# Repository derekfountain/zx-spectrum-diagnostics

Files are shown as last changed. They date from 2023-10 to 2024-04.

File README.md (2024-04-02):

# 16K/48K ZX Spectrum Diagnostics Board

This is a hardware diagnostics board for the 16K and 48K ZX Spectrum,
based on two Raspberry Pi Pico microcontroller boards.

The idea is that given a Spectrum of unknown provenance (an eBay
purchase maybe), this device can quickly tell you what potential
issues the Spectrum might have. It's limited to what it can see on the
rear edge connector, so it can't detect broken tracks or things like
that, but it can report a fair amount of useful information. There are
no guarantees, of course.

The board plugs into the Spectrum's rear edge connector, and has an OLED
screen and a single user-interface button:

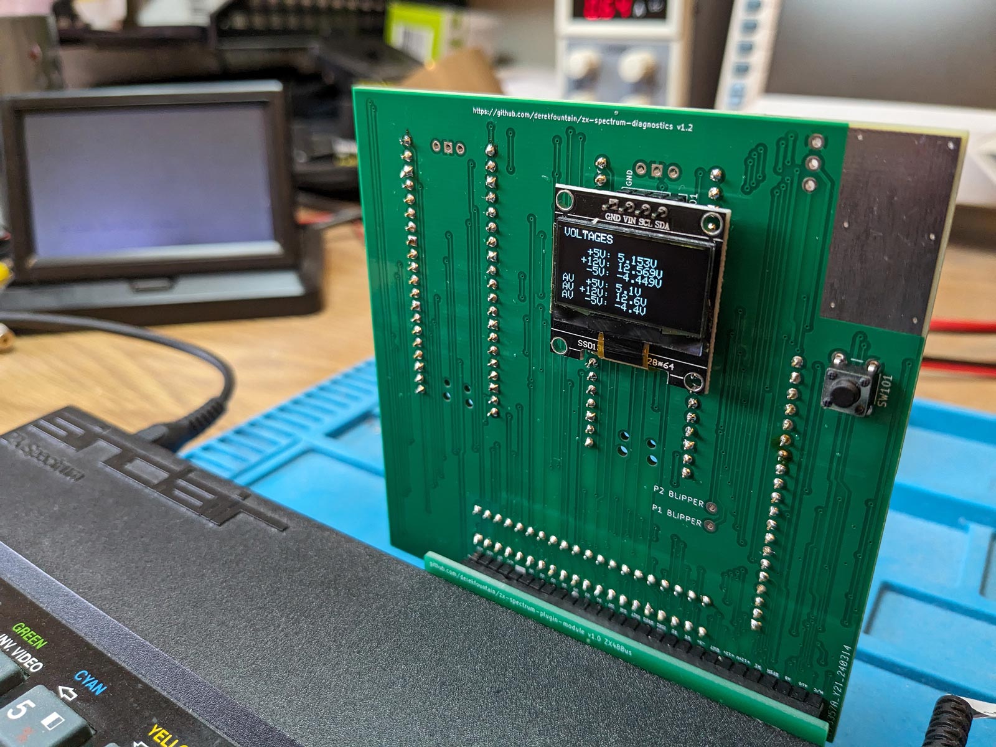
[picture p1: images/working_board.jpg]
v1.2


The rear of the board carries the Picos and some header sockets (discussed below):

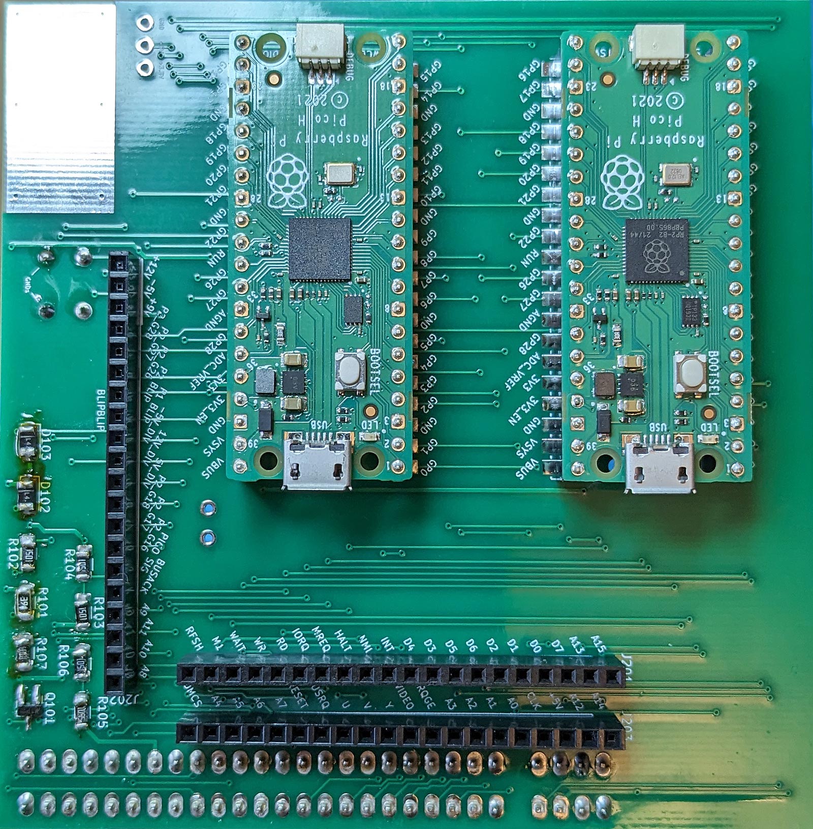
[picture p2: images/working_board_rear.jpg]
v1.2 rear


The board is powered by the Spectrum. You just plug it in and turn the
Spectrum on. It will (repeatedly) run a set of tests on the signals it
sees on the rear edge connector. The tests are divided into pages. Pressing
the button advances to the next page of tests.

Click through for a brief demonstration:

IMAGE ALT TEXT (https://www.youtube.com/watch?v=3YdgdeM5kM0 "ZX Spectrum Hardware Diagnotics Interface")

https://www.youtube.com/watch?v=3YdgdeM5kM0

## Status

As of March 2024, v1.2 is functionally complete. The KiCAD project here is current up
to v1.3 which just has a couple of silkscreen fixes.

There is plenty of scope to upgrade the tests the board runs, so updates
might appear in future. For now the board is complete.

[Derek Fountain](https://www.derekfountain.org/), March 2024

# Operation

The Spectrum is usable when the device is displaying the voltages page.
The tests which run on the other pages constantly reset the Spectrum
so it can't be used when any of those are showing.

The pages, and the tests run, are as follows. You might find it useful to
read the [Spectrum Service manual](https://spectrumforeveryone.com/wp-content/uploads/2017/08/ZX-Spectrum-Service-Manual.pdf)
in conjunction with the following.

## Voltages Page

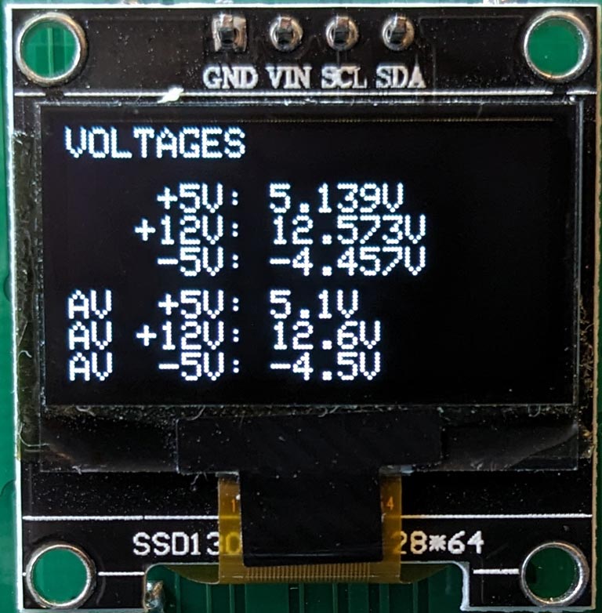
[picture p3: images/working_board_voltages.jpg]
voltages


Voltages are the first thing we look at when faced with a broken ZX Spectrum.
There are four voltages used: the input from the PSU, which is nominally +9V
and isn't analysed by the Picos; the main +5V supply for the Spectrum board;
the +12V supply for the RAM and video subsystem; and the -5V supply for the
RAM.

The OLED screen shows the voltages on the rear edge connector.
That's not the same as what's going on at the RAM chips! But it's a very good
indication, especially when you see faults being reported.

The top three lines of the display show the voltages as detected by the Pico's
analogue to digital converters. These values update several times a second. The
bottom three lines show the averages for those values over the last 100
samples. Note that the further the voltages get from the expected values, the
less accurate the reported values will be. This is because the circuitry on the
board is designed to protect the Picos from rogue voltages, as opposed to
providing accurate results in all circumstances.

The Picos are powered from the Spectrum's +5V so if that's not working
the Picos won't turn on and you probably won't have got this
far. Assuming the plug on the PSU is outputting 9V to 14V as you'd
expect, you probably have a faulty 7805 regulator.

The +12V and -5V supplies come from the Spectrum's internal DC/DC
converters. They're known to be a bit wobbly, and the -5V supply in particular
has a rather wide tolerance (-5.5V to -4.0V, see the service manual).

Here's a screen showing the voltages from a broken Spectrum. The -5V supply is
within specification, but the 12V supply is broken:

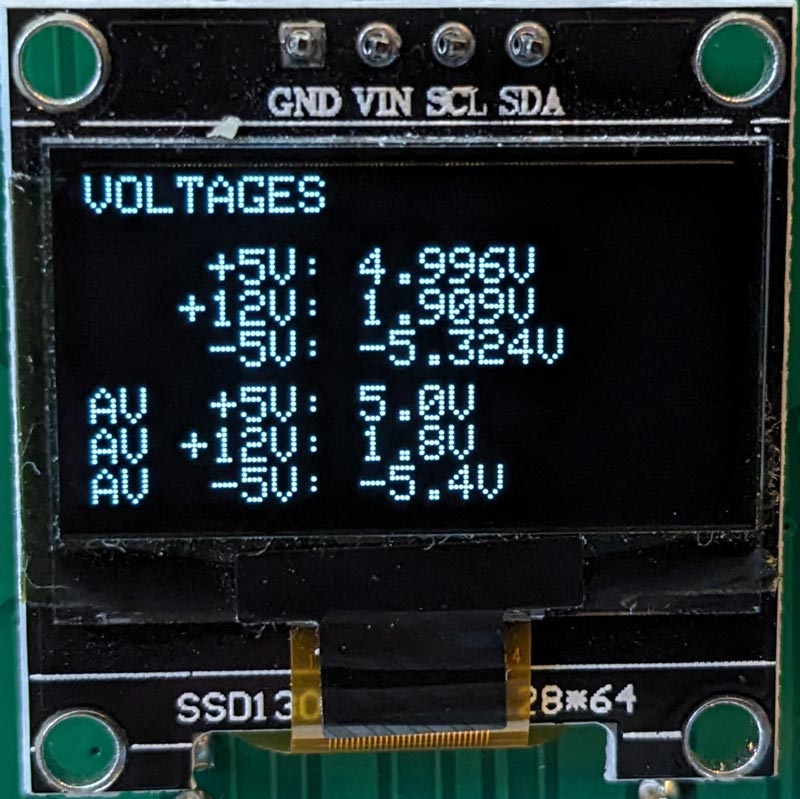
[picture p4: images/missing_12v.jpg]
missing 12V


Note: if the Spectrum's internal voltage regulator has failed in such
a way that the Spectrum's internal +5V supply is too high, that high
voltage will be fed into the Picos and might destroy them. The maximum
they can take is +5.5V. I've never heard of a 7805 regulator failing
in this way, and if one does the Spectrum it's inside will be very
dead, but if you think it might have happened you should check the +5V
on the edge connector before connecting the Picos to it. (Remove the
Picos, plug the board in to the Spectrum, then check the +5V line at
any of the +5V sample points.)

## ULA Page

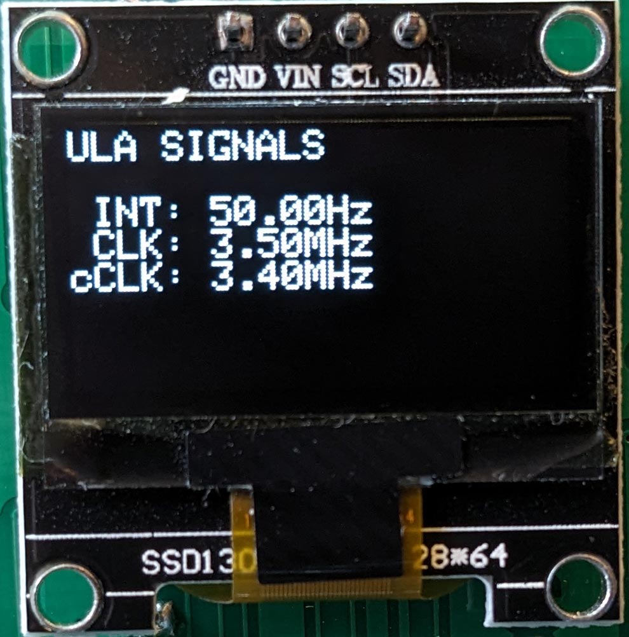
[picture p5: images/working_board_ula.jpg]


The ULA does a lot of stuff inside the Spectrum, and can fail in whole
or in part. i.e. some parts of its internal circuitry can be working while other
parts are dead. A partially working ULA can be rather puzzling to
diagnose. The tests on the diagnostics board only test the clocks the
ULA is emitting.

The INT clock is the Spectrum's interrupt clock. It's used to generate
both the TV picture and the Z80's interrupt signal. What's sampled
from the edge connector is directly from the ULA and should be exactly
50Hz.

The CLK is the Z80's clock, which is also generated by the ULA. This should be
3.5MHz. The diagnostics board samples the signal using the RP2040's PIOs, and
is (internally) accurate to a single clock cycle. This is sampled with the Z80
held in reset, so the Spectrum's notorious memory contention doesn't get in
the way (see next item).

The cCLK is the contended clock, which is the clock signal the ULA provides for
the Z80 when the ULA and memory chips clash trying to read lower memory. This will
always be slightly slower than the CLK signal. This is sampled when the Z80 is
allowed to run normally, which means the ROM code is running and is updating
the screen and system variables which are in lower RAM. Some contention should
always be reported. Holding the space key down while the test is running
changes the contention pattern:

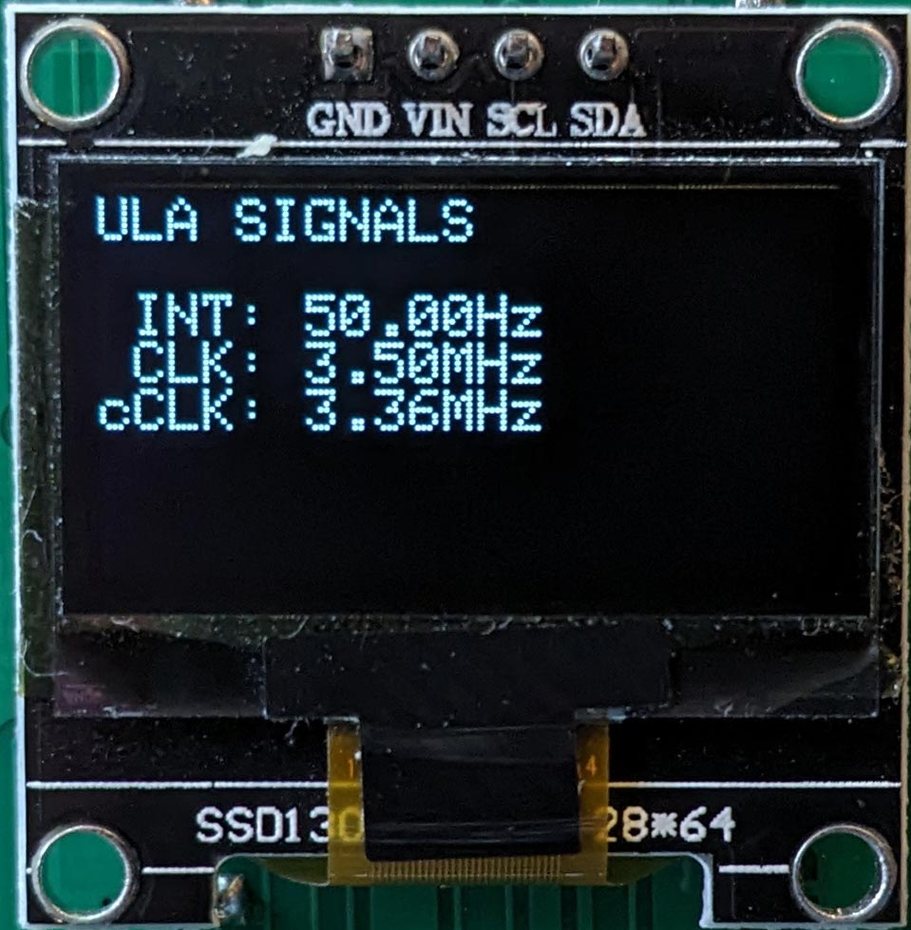
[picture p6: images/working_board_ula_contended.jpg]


## Z80 Page

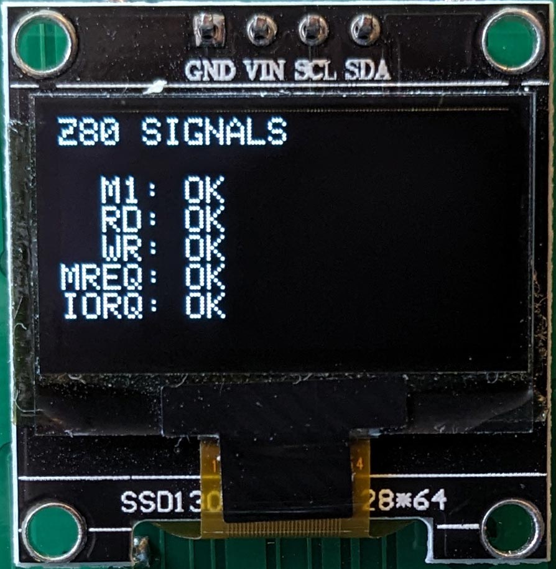
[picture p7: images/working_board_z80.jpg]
Z80


A subset of the Z80 signals are exposed on the Spectrum's rear edge connector:
read, write, memory read, and I/O request. Their exact behaviour aren't analysed (but
could be).

The Spectrum is allowed to start normally, then the Z80 signals are checked to ensure
they are transiting from low to high state, and from high to low state. Any
stuck signal will be reported, and would explain a failure of the Spectrum. Look for
solder bridges from botched repairs, or broken tracks.

The M1 line is an exception. Sinclair used some Z80s with non-functioning M1 signals,
and machines with those faulty Z80s can't drive certain peripherals like the Interface
One and my [recreated ZX Spectrum Expansion System](https://www.derekfountain.org/zses.php). The Spectrum can otherwise function
correctly, so a fault reported with the M1 line isn't that unusual and doesn't indicate
a fault which would stop the machine working.

## Data Bus Page

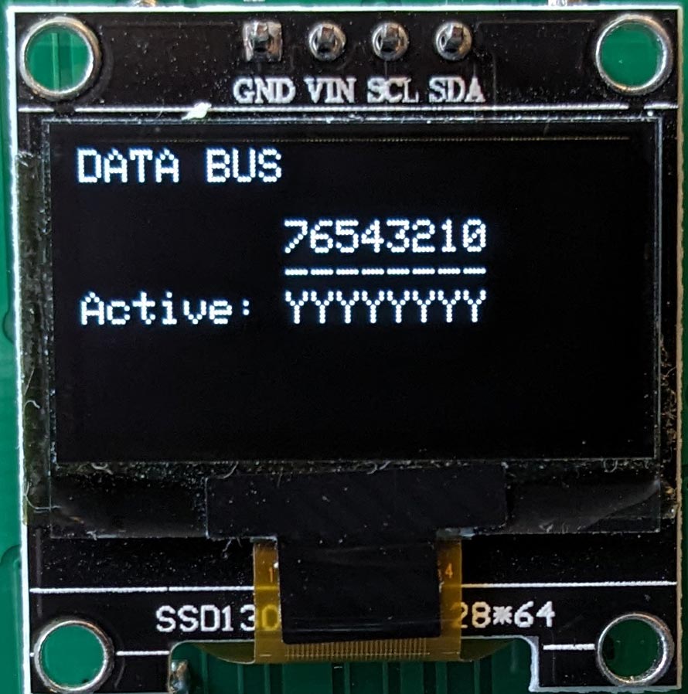
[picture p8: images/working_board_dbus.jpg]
Data Bus


This test allows the Spectrum to start normally, then the Z80 data bus signals are
checked to ensure they are transiting from low to high state, and from high to low
state. Any stuck signal will be reported, and would explain a failure of the Spectrum.
The most likely cause would be a faulty memory chip holding its output bit high or
low, but also look for solder bridges from botched repairs, or broken tracks.

If the Spectrum has a faulty ROM or some other unusual fault it would still be likely
that whatever was appearing on the data bus would consist of state changes of all the
lines, at least occasionally. Therefore this test should be able to indicate stuck
lines reasonably reliably even in the presence of other faults.

## Address Bus Page

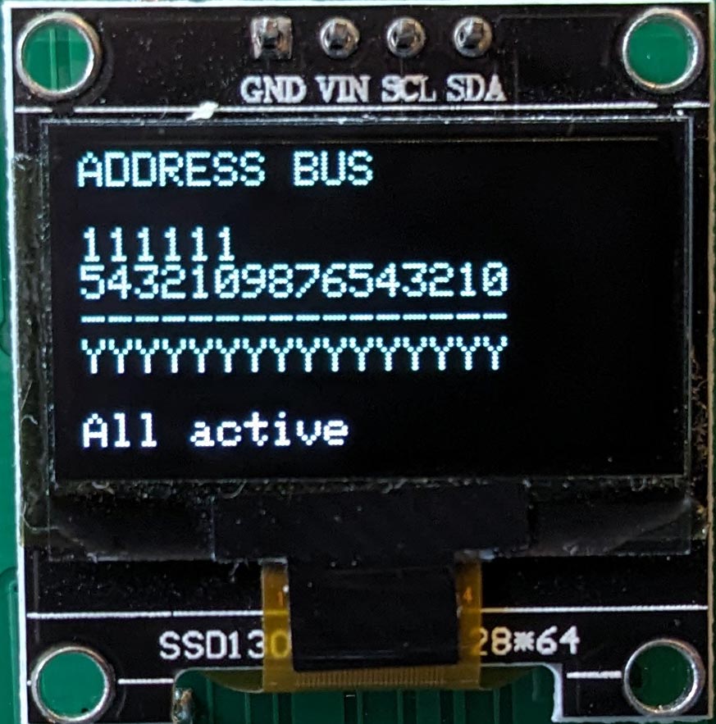
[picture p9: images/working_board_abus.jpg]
Address Bus


This test allows the Spectrum to start normally, then the Z80 address bus signals are
checked to ensure they are transiting from low to high state, and from high to low
state. Any stuck signal will be reported, and would explain a failure of the Spectrum.

The early code in the Spectrum's ROM does a RAM check which writes and reads from the
whole 64K address space, so all the address lines should transit within a second or so
of the machine starting up.

The ULA's signals on the address bus aren't exposed on the edge connector. What is
reported here is the Z80's perspective.

## ROM Page

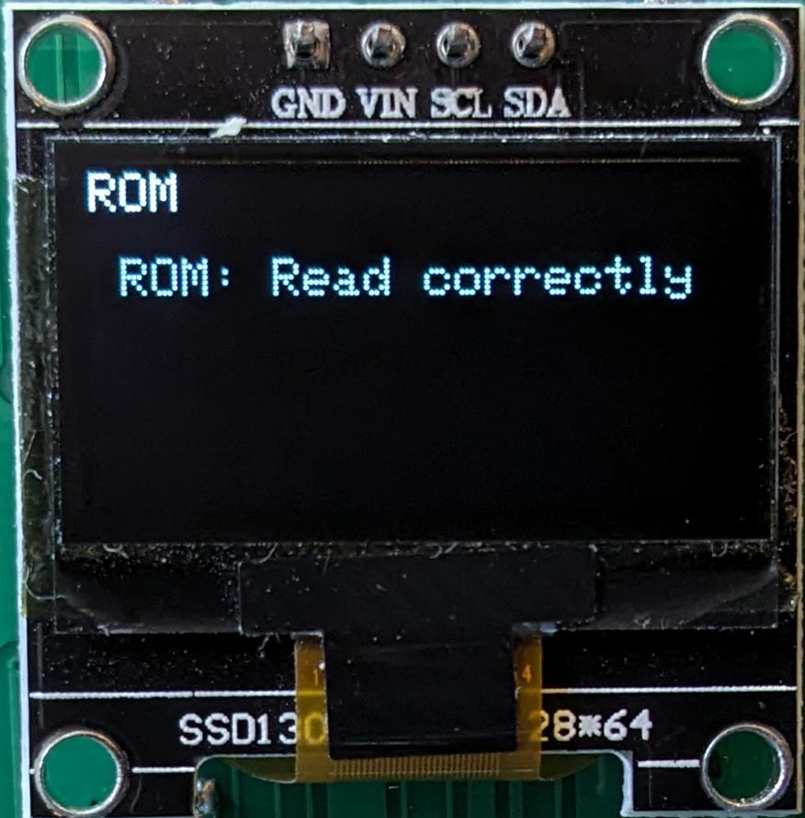
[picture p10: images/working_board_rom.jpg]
ROM


This page runs a single test which checks whether the ROM appears to be providing
the correct data to the Z80 (i.e. the program which implements the Spectrum's BASIC
interpreter).

It allows the Spectrum to start, then samples the address bus watching for reads of
bytes from the ROM. Those addresses are collected, then analysed to see if they follow
the expected pattern. The Z80 code at the start of the Spectrum's ROM disables
interrupts, primes a couple of registers, then jumps to an absolute (hardcoded)
location. It's therefore possible to check whether the Z80 is requesting the bytes at
0x0000 to 0x0007 one at a time in sequence, then requests the byte at 0x11CB (which is
where the jump goes to) and so on.

It only samples a couple of dozen addresses to check the Z80 is following the expected
sequence, but if it is that means the Z80, and its control, data and address buses
are all functioning correctly or very close to correctly.

# ZX Signal Headers

The board has 3 rows of 20 pins which make accessible the Z80 and
Spectrum control signals which are on the rear edge connector, plus a
few more from the board itself.  They're labelled J201, J202 and
J203. All except one (~12V) of the Spectrum's edge connector signals
are brought out to these connectors (and that missing ~12V line could
now be fixed because after a juggle around I found a couple of spare
connections - see the errata.txt file).

These headers allow jumper wires to be inserted which enable easy
connection to a meter or oscilloscope. I've found this very
handy. This photo shows oscilloscope probing of the Z80 clock and
another signal from a board I got from eBay. Note the silver tab on
the corner of the board is a ground point for attaching clips to.

Scoping signals

# Bill of Materials

This is a simple build. You will need:

3x [3216 SMD Diode](https://www.mouser.co.uk/ProductDetail/581-SD1206S040S2R0)
Schottky Diode for Pico input protection and 12V clamping
<br>
1x [PMBT2222A SMD Transistor](https://www.mouser.co.uk/ProductDetail/771-PMBT2222A-T-R)
NPN Transistor for /RESET
<br>
1x [3216 SMD 1K Resistor](https://www.mouser.co.uk/ProductDetail/603-RT1206FRE071KL)
1K Resistor for /RESET
<br>
3x [3216 SMD 1K5 Resistor](https://www.mouser.co.uk/ProductDetail/603-RT1206FRE071K5L)
1K5 Resistor for the voltage dividers
<br>
1x [3216 SMD 390R Resistor](https://www.mouser.co.uk/ProductDetail/603-RT1206FRE07390RL)
390R Resistor for the voltage divider
<br>
1x [3216 SMD 5K6 Resistor](https://www.mouser.co.uk/ProductDetail/603-RT1206FRE075K6L)
5K6 Resistor for the voltage divider
<br>

Also, from your parts bin:

2x Raspberry Pi Pico with pins and sockets if you want them
<br>
1x 4-pin header and socket for mounting the screen
<br>
1x SPST switch. Any single pole, single throw switch should do for the user input
<br>
1x 0.96" OLED display (SSH1106 based if you want to use my code)

Note that the OLED screen I used is SSH1106 based. It's actually got SSD1306
printed on it, which was an unpleasant surprise at the time. If you want to
use one of the more common SSD1306 based screens the software will need
updating. It's only displaying text so that shouldn't be too difficult.

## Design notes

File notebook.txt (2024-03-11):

AM says I can measure the -5V rail with

  +5V--------+----------
             |         
             |         
                       
            R1         
                       
             |         
             |         
             +---------- V(measured)
             |         
             |         
                       
            R2         
                       
             |         
             |         
  -5V--------+----------

If I know 5V then 

V(-5) = 2*V(measured) - V(5)

Example:

+5V is 5.00
-5V is -1.00

That's 3V dropped across each resistor (6V dropped in total).
So 3V dropped across R1.
Measured voltage will be 5.00-3.00=2.00

V(-5) = 2*2.00 - 5.00

V(-5) = 4-5 = -1

So it seems to work.

It makes sense. V(measured) is the voltage across one resistor, so
if the resistors are the same then double that is the voltage across
both resistors, which is +5V to -5V.

AM added that a diode is needed to protect it in case -5V is there
but +5 isn't. And another for the positive side.

  +5V--------+----------
             |         
             |         
                       
            R1     3V3 
                    |  
             |      D2 
             |      |  
             +---------- V(measured)
             |      |  
             |     D1  
                    |  
            R2     GND 
                       
             |         
             |         
  -5V--------+----------

In this case, with +5V at 0V, without D2 there's a potential difference
between the Pico pin (set as input) and the -5V rail, so 
current would follow out of the Pico to -5V. That would probably
not do the Pico any good, so the diode will stop it. The current would
flow from GND, through D1 and R2, to -5V.

If -5V were to fail, but +5V remained (assume a broken track or something)
then 5V would flow through R1, and 1V8 would flow to the 3V3 rail via D2.
That would put 3V3 into the Pico's ADC.

Forward voltage of 1N4148 is 0.72V so that needs to be taken
into account, somehow.

 Extra note, though. On the Spectrum the 5V comes from the 7805, and
 isn't particularly precise. I have 4.85V on one of mine, and the -5V
 circuit is generating -5.01V. Which means there's 9.86V across the
 whole divider and the centre point is at 4.93V. Subtracting 5V from
 that results in -0.07V. That's what's going into the ADC, which
 reads it at zero, hence the final output value is an unmoving -5.000V.
 One of my boards has a measured -0.270V at the divider mid-point.

 Since the only 5V I have is actually from the system under test, I'm
 going to change the top of the divider to the 3V3 from the Pico, which
 is much more precise. I'll need to tweak the divider to keep it
 balanced.

 Further, the Pico pad can only tolerate a minimum of -0.5V, so I need
 to be careful. The clamping diodes would typically have a forward
 voltage of 0.7V so I could end up with -0.7V going into the Pico.
 I'll change the diodes to schottky ones. The lower VF should keep
 that clamped voltage at a minimum of -0.3V to -0.5V.

I need to change the voltage divider to have the Pico's 3V3 at the top
and the ZX -5V at the bottom. I want to restrict the centre point,
which is the input to the ADC, to 0V to 3V3 where possible, and
definitely for each typical use case. Trial and error led me to
R1=390R and R2=1K5.

Using Digikey's voltage divider calculator, I worked out the following:

Typical:

3V3 to -5V0 = 8V3 total drop

R1=390R R2=1K5
R1 drops 1.7126984127
R2 drops 6.5873015873

Vout = 3.3 - 1.7126984127 = 1.58730 into the ADC

Measured on AM board:

3.27V to -5.44V = 8.71V total drop

R1=392R R2=1498R

Calculator says:
R1 drops 1.80652
R2 drops 6.90348

Vout = 3.27 - 1.80652 = 1.46348V into the ADC

Measured on DVM:
R1 drops 1.794V
R2 drops 6.900V

Vout = 3.27 - 1.794 = 1.476V should be into the ADC, measured 1.478V
So that works very well

-5V broken, at 0V:

3V3 to 0V = 3V3 total drop

R1=390R R2=1K5
R1 drops 0.680952381
R2 drops 2.619047619

Vout = 3.3 - 0.680952381 = 2.619047619 into the ADC

-5V broken, at +1V:

3V3 to 1V = 2V3 total drop

R1=390R R2=1K5
R1 drops 1.4746031746
R2 drops 1.8253968254

Vout = 3.3 - 1.4746031746 = 1.8253968254 into the ADC

-5V broken, at +5V:

3V3 to 5V = -1.7 total drop

R1=390R R2=1K5
R1 drops -0.350794
R2 drops -1.3492063492

Vout = 3.3 - -0.350794 = 3.650794 into the ADC
If that makes sense then the clamping diodes would be required

-5V broken, at +12V:

3V3 to 12V = -8.7 total drop

R1=390R R2=1K5
R1 drops -1.79524
R2 drops -6.9047619048

Vout = 3.3 - -1.79524 = 5.09524 into the ADC
If that makes sense then the clamping diodes would be required

These negative voltages aren't intuative, so I have to trust the equation.
I've little clue if what's going to come out of the thing is what I've
calculated.

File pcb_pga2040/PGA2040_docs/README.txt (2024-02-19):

I found the PGA2040 symbol and footprint I've used in this project here:

https://github.com/koron/yuiop/tree/main/yuiop60pi/main3

The licence for that project is:

The MIT License (MIT)

Copyright (c) 2021 MURAOKA Taro <koron.kaoriya@gmail.com>

Permission is hereby granted, free of charge, to any person obtaining a copy
of this software and associated documentation files (the "Software"), to deal
in the Software without restriction, including without limitation the rights
to use, copy, modify, merge, publish, distribute, sublicense, and/or sell
copies of the Software, and to permit persons to whom the Software is
furnished to do so, subject to the following conditions:

The above copyright notice and this permission notice shall be included in
all copies or substantial portions of the Software.

THE SOFTWARE IS PROVIDED "AS IS", WITHOUT WARRANTY OF ANY KIND, EXPRESS OR
IMPLIED, INCLUDING BUT NOT LIMITED TO THE WARRANTIES OF MERCHANTABILITY,
FITNESS FOR A PARTICULAR PURPOSE AND NONINFRINGEMENT. IN NO EVENT SHALL THE
AUTHORS OR COPYRIGHT HOLDERS BE LIABLE FOR ANY CLAIM, DAMAGES OR OTHER
LIABILITY, WHETHER IN AN ACTION OF CONTRACT, TORT OR OTHERWISE, ARISING FROM,
OUT OF OR IN CONNECTION WITH THE SOFTWARE OR THE USE OR OTHER DEALINGS IN
THE SOFTWARE.

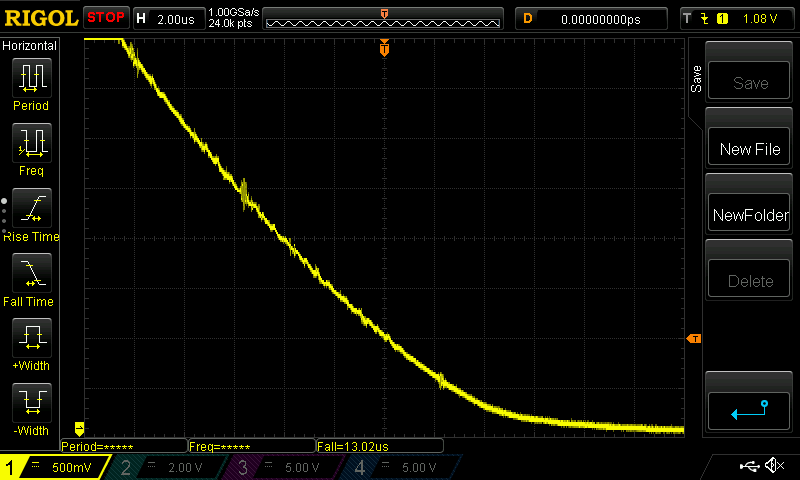
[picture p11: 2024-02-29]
images/z80_reset_line.png

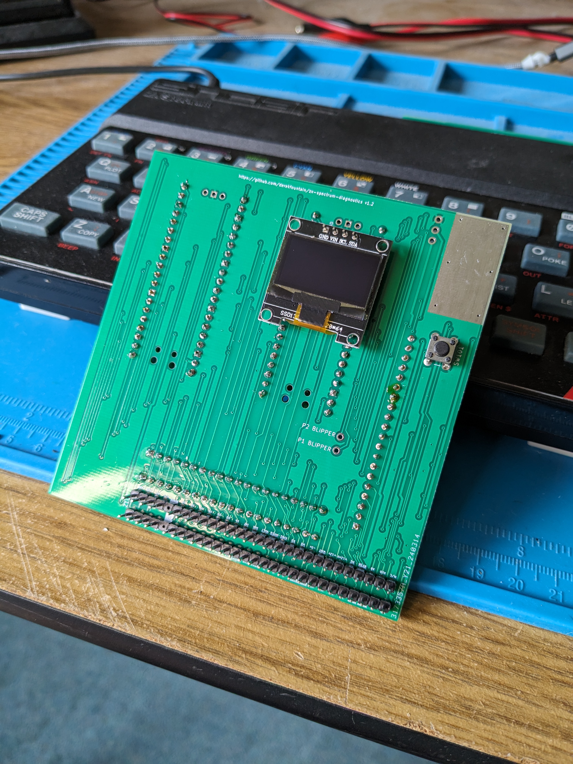
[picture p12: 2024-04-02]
images/video_front.jpg

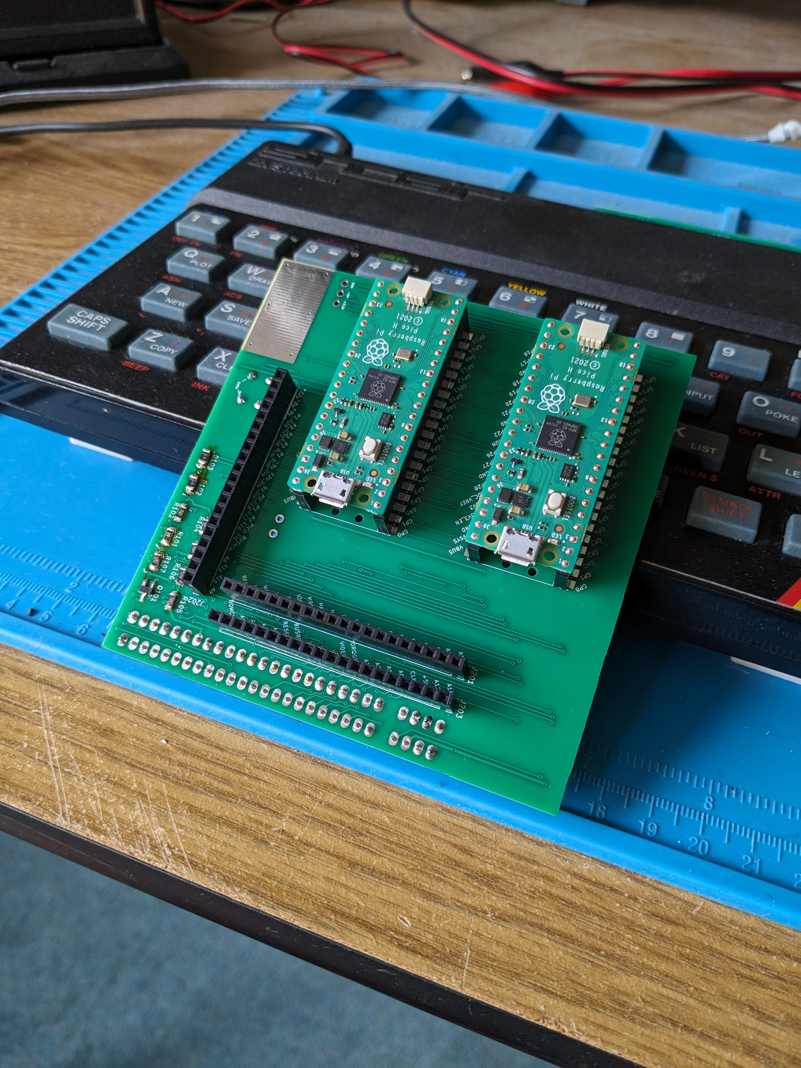
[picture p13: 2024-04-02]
images/video_back.jpg

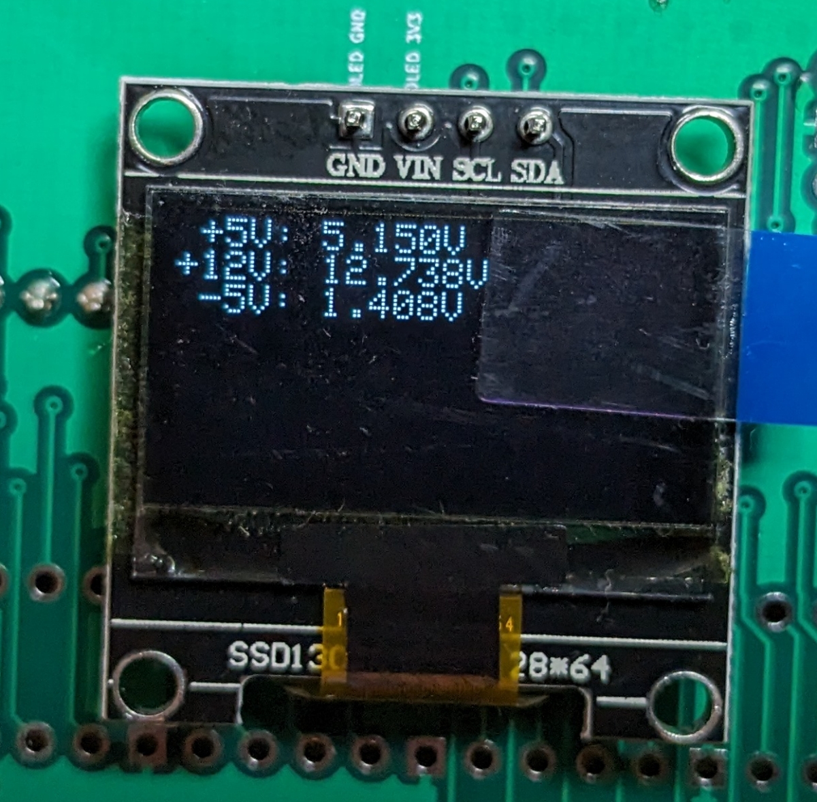
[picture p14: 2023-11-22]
images/faulty_min5_board_voltages.jpg

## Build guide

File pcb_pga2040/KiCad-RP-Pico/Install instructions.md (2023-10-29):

# Install instructions

## 1. Copy the files locally

Copy the `RP-Pico Libraries` folder wherever you like on your computer.

## 2. Install the Raspberry Pi Pico board schema symbol

Use the `KiCad | Preferences | Manage Symbol Libraries...` command to manage the symbol library:

symbol library manager

then select the global tab and click on the folder button:

symbol library manager

navigate to the `RP-Pico Libraries` folder, select the `MCU_RaspberryPi_and_Boards.kicad_sym` file and open it:

symbol library manager

et voilà, the first step is completed:

symbol library manager

You can now close the symbol libraries manager window.

## 3. Install the Raspberry Pi Pico board footprint

You can use a similar approach to add the footprint to the footprint libraries manager, but I've found some issues that I've solved using the footprint editor, so here are the steps I suggest you to follow:

Open the footprint editor

symbol library manager

wait for the footprints to load... then use the `File | Add Library` command:

symbol library manager

confirm the `Global` choice:

symbol library manager

and select the `MCU_RaspberriPi_and_Boards.pretty` folder (yes, the folder represent a footprint library on KiCad):

symbol library manager

Now the library is installed on KiCad with the Raspberry Pi Pico footprint (double click on it to see it on the editor pane):

symbol library manager

Don't close the windows as the next step start from here.

## 4. Install the Raspberry Pi Pico board footprint 3D visual

If not already open, open the the footprint editor

symbol library manager

double click on the `RPi_Pico_SMD_TH` footprint from the `MCU_RaspberriPi_and_Boards` library and then click on the `Footprint properties` icon:

symbol library manager

In the footprint properties window, first select the `3D Settings` tab. Please note that the preview shows only the PCB board with the footprint added on step 3, without any 3D representation of the Raspberry Pi Pico board. Now click on the folder icon to add the 3D model:

symbol library manager

Navigate to the `RP-Pico Libraries` folder, select the `Pico.wrl` file and wait until the model is shown in the right panel, then confirm with OK:

symbol library manager

The model is already scaled and translated to match the footprint:

symbol library manager

now close the `Footprint Properties` window, and the `Footprint Editor`, obviously saving the changes.

## Conclusion

Now that you've installed the schema and footprint and added the 3D model to the footprint, you can use the Raspberry Pi Pico board on your KiCad projects.

I've also added a test KiCad Project on the `Test` folder, that you can use to see an example of it.

Have fun!

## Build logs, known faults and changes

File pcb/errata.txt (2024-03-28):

v1.0 First board sent for fabrication
=====================================

Wrong footprint for the Spectrum edge connector. I used
zxbus:ZX_Bus_Pin_Header, which is two rows of pin headers about
2.5mm apart. They should be 5mm apart.

In my previous projects I appear to have modified the footprint
myself. I only vaguely remember doing it, but I think I did. I
didn't copy that footprint out to this project, I used the one
from the library which is too small.

Further, the holes are too small. They were a tight fit previously
but I've bought 200 header rows from China and it appears their pins
are very slightly larger and they don't fit in the holes.

I think the solution is to use zxedge:Spectrum_Edge_Connector, which is
the correctly spaced footprint, which larger holes. I can't remember
where I got this library from, so it's another punt.
:: Fixed

I forgot the label in the silkscreen. Need to add a v1.1 to the next one.
:: Fixed

Break the signals which would do damage to the Pico out to another
connector header, so they aren't so easy to get wrong. +5V, -5V, +9V and
+12V are the obvious ones. There might be others.
:: Fixed, I move them to the end of the connector and marked them 
   in the silk screen

Wire /INT up to GPIO15 on Pico1. I have the test for this and it
correctly sees 50Hz.
:: Done

Wire /CLK up to GPIO14 on Pico1. Tests for contended and noncontended
frquencies are in place.
:: Done

Wire up ZXHALT to GPIO13 on Pico1. Will reveal if Z80 is stuck in a
HALT lock (Z80 has execute HALT with interrupts disabled).
:: Decided against, low value test. HALT is on the socket connector

Wire up ZXNMI to GPIO12 on Pico1. Will reveal if Z80 is stuck with
incoming NMIs.
:: Decided against, low value test. NMI is on the socket connector

Wire up ZXM1 to GPIO11 on Pico1. Will reveal if Z80 is one with broken M1.
:: Done

v1.1 Second board, has the correct edge connector footprint
===========================================================

I'm only using a single input button. Remove the other, reclaim
the GPIO.
: Done on v1.2

Missing off /IORQ was a mistake. Use the GPIO freed up by removing
the second user button to connect this signal to the Pico.
: Done on v1.2

The second Pico needs to collect addresses that appear on the address
bus. To do that it needs to see the MREQ, RD and CLK lines, so it
can tell when a valid address is ready for it to pick up.
: Done on v1.2
: On development board I've connected MREQ, RD and CLK to GPIOs
16, 17 and 18. Matches the modification to the schematic and PCB
layout for v1,2.

It needs a GND pad on the top or side. Linking up a scope probe is
to ZX GND currently rather hard.
: Done on PCB

Due to the standard 1N4148 diodes I used for clamping the -5V input
to the Pico, I have the possibility of -0.7V going into the ADC.
The minimum allowed by the Pico is -0.5V. Change the clamping diodes
to schottky ones to keep the clamp at -0.3V to -0.5V.
: Done on schematic, footprint updated on PCB

The top of the -5V voltage divider comes from +5V, which is from the
system under test and hence isn't reliable. Change it to +3.3V from
the Pico, which is precise. Rebalance the voltage divider and ensure
it works as expected.
: All done on schematic and PCB. Top of the -5V divider is now 3V3
from the Pico, R1 is 390R and R2 remains 1K5. Code has been updated
and tested with a patched v1.1 board, seems to work.

v1.2 Third Pico based board
===========================

A couple of extraneous P1/P2 blipper labels in the silkscreen need
removing.
: Done

The silkscreen for J202 had (the duplicated) MREQ, RD and CLK
mislabelled.
: Done

v1.3 Fourth Pico based board
============================

I haven't had one of these made up yet. So far it's only silkscreen
tweaks.

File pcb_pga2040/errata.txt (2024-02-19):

This project forked from the original, Pico based project
at that project's v1.1.

v1.1 Second board, has the correct edge connector footprint
===========================================================

I'm only using a single input button. Remove the other, reclaim
the GPIO.
: To be confirmed.

Missing off /IORQ was a mistake. Need to find a way to get
that back. The button2 GPIO is the obvious option.

Remove the Picos

Add two PGA2040s

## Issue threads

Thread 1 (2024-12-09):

Address Bus decode

PicoElements, 2024-12-09:
Hi Derek, i'm new to sinclair and i'd like to ask you if there is a way to decode address bus stuck lines.
In mine i have three "L" under the first "098" left digits.
Could you give me an advice?

Thanks,
Stefano

derekfountain, 2024-12-09:
There's no "decode" to do. Those 3 lines being marked as 'L' mean the lines are being seen by the Pico as not changing voltage, they are permanently set at low voltage. Something in the Z80 or the Spectrum circuit is holding the lines low. Or the diagnostics board is faulty - that's always possible.

An issue ticket for my project is not the place to get help trying to fix a broken Spectrum. I suggest you go to the Spectrum Computing hardware forum here:

https://spectrumcomputing.co.uk/forums/viewforum.php?f=22

and ask there. Someone will help you. It'll probably be me, but at least it'll be in the right place. :)

PicoElements, 2024-12-09:
Hi Derek, really sorry for that. Thanks for your help and i will post on the forum for sure.

Regards,
Stefano

PicoElements, 2024-12-09:
Wrong place, not an issue but troubleshooting info.

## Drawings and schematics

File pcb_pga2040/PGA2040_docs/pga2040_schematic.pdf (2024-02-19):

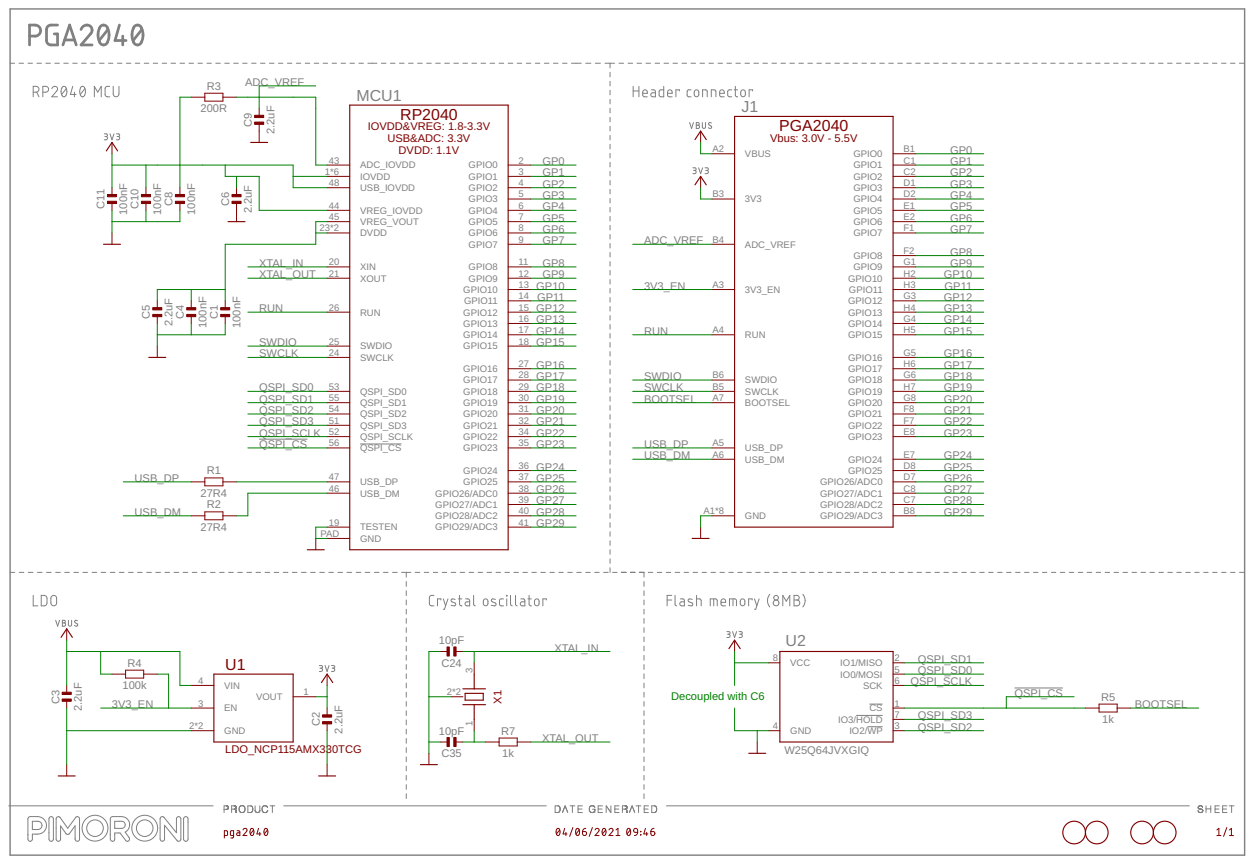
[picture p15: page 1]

2.2u2F.2uF W25Q64JVXGIQ 10pF 10pF 100nF 100nF 2.2uF 2.2uF 100nF 100nF 100nF 27R4 27R4 2.2u200R F 1k 100k 1k IOVDD 1*6 DVDD 23*2 GND PAD QSPI_SD0 53 QSPI_SD1 55 QSPI_SD2 54 QSPI_SD3 51 QSPI_SCLK 52 QSPI_CS 56 VREG_IOVDD 44 VREG_VOUT 45 USB_DP 47 USB_DM 46 SWCLK 24 SWDIO 25 RUN 26 XIN 20 XOUT 21 TESTEN 19 ADC_IOVDD 43 USB_IOVDD 48 GPIO0 2 GPIO1 3 GPIO2 4 GPIO3 5 GPIO4 6 GPIO5 7 GPIO6 8 GPIO7 9 GPIO8 11 GPIO9 12 GPIO10 13 GPIO11 14 GPIO12 15 GPIO13 16 GPIO14 17 GPIO15 18 GPIO16 27 GPIO17 28 GPIO18 29 GPIO19 30 GPIO20 31 GPIO21 32 GPIO22 34 GPIO23 35 GPIO24 36 GPIO25 37 GPIO26/ADC0 38 GPIO27/ADC1 39 GPIO28/ADC2 40 GPIO29/ADC3 41 MCU1 C2 C3 VCC 8 IO1/MISO 2 IO0/MOSI 5 GND 4 SCK 6 IO2/WP 3 IO3/HOLD 7 CS 1 U2 1 3 2*2 C24 C35 C1 C4 C5 C6 C8 C10 C11 R1 R2 C9 R3 VIN 4 GND 2*2 EN 3 VOUT 1 R7 GND A1*8 USB_DP A5 USB_DM A6 SWCLK B5 SWDIO B6 RUN A4 GPIO0 B1 GPIO1 C1 GPIO2 C2 GPIO3 D1 GPIO4 D2 GPIO5 E1 GPIO6 E2 GPIO7 F1 GPIO8 F2 GPIO9 G1 GPIO10 H2 GPIO11 H3 GPIO12 G3 GPIO13 H4 GPIO14 G4 GPIO15 H5 GPIO16 G5 GPIO17 H6 GPIO18 G6 GPIO19 H7 GPIO20 G8 GPIO21 F8 GPIO22 F7 GPIO23 E8 GPIO24 E7 GPIO25 D8 GPIO26/ADC0 D7 GPIO27/ADC1 C8 GPIO28/ADC2 C7 GPIO29/ADC3 B8 J1VBUS A2 3V3 B3 BOOTSEL A7 3V3_EN A3 ADC_VREF B4 R4 R5 USB_DP USB_DP USB_DM USB_DM QSPI_SD1 QSPI_SD1 QSPI_SD2 QSPI_SD2 QSPI_SD3 QSPI_SD3 QSPI_SCLK QSPI_SCLK QSPI_CS QSPI_CS XTAL_IN XTAL_IN XTAL_OUT XTAL_OUT QSPI_SD0 QSPI_SD0 ADC_VREF ADC_VREF SWDIO SWDIO SWCLK SWCLK GP2 GP2 GP3 GP3 GP0 GP0 GP1 GP1 GP4 GP4 GP5 GP5 GP6 GP6 GP7 GP7 GP8 GP8 GP9 GP9 GP10 GP10 GP11 GP11 GP12 GP12 GP13 GP13 GP14 GP14 GP15 GP15 GP16 GP16 GP17 GP17 GP18 GP18 GP19 GP19 GP20 GP20 GP21 GP21 GP22 GP22 GP23 GP23 GP24 GP24 GP25 GP25 GP26 GP26 GP27 GP27 GP28 GP28 GP29 GP29 RUN RUN 3V3_EN 3V3_EN BOOTSEL BOOTSEL RP2040 IOVDD&VREG: 1.8-3.3V USB&ADC: 3.3V DVDD: 1.1V X1 U1 LDO_NCP115AMX330TCG PGA2040 Vbus: 3.0V - 5.5V Decoupled with C6

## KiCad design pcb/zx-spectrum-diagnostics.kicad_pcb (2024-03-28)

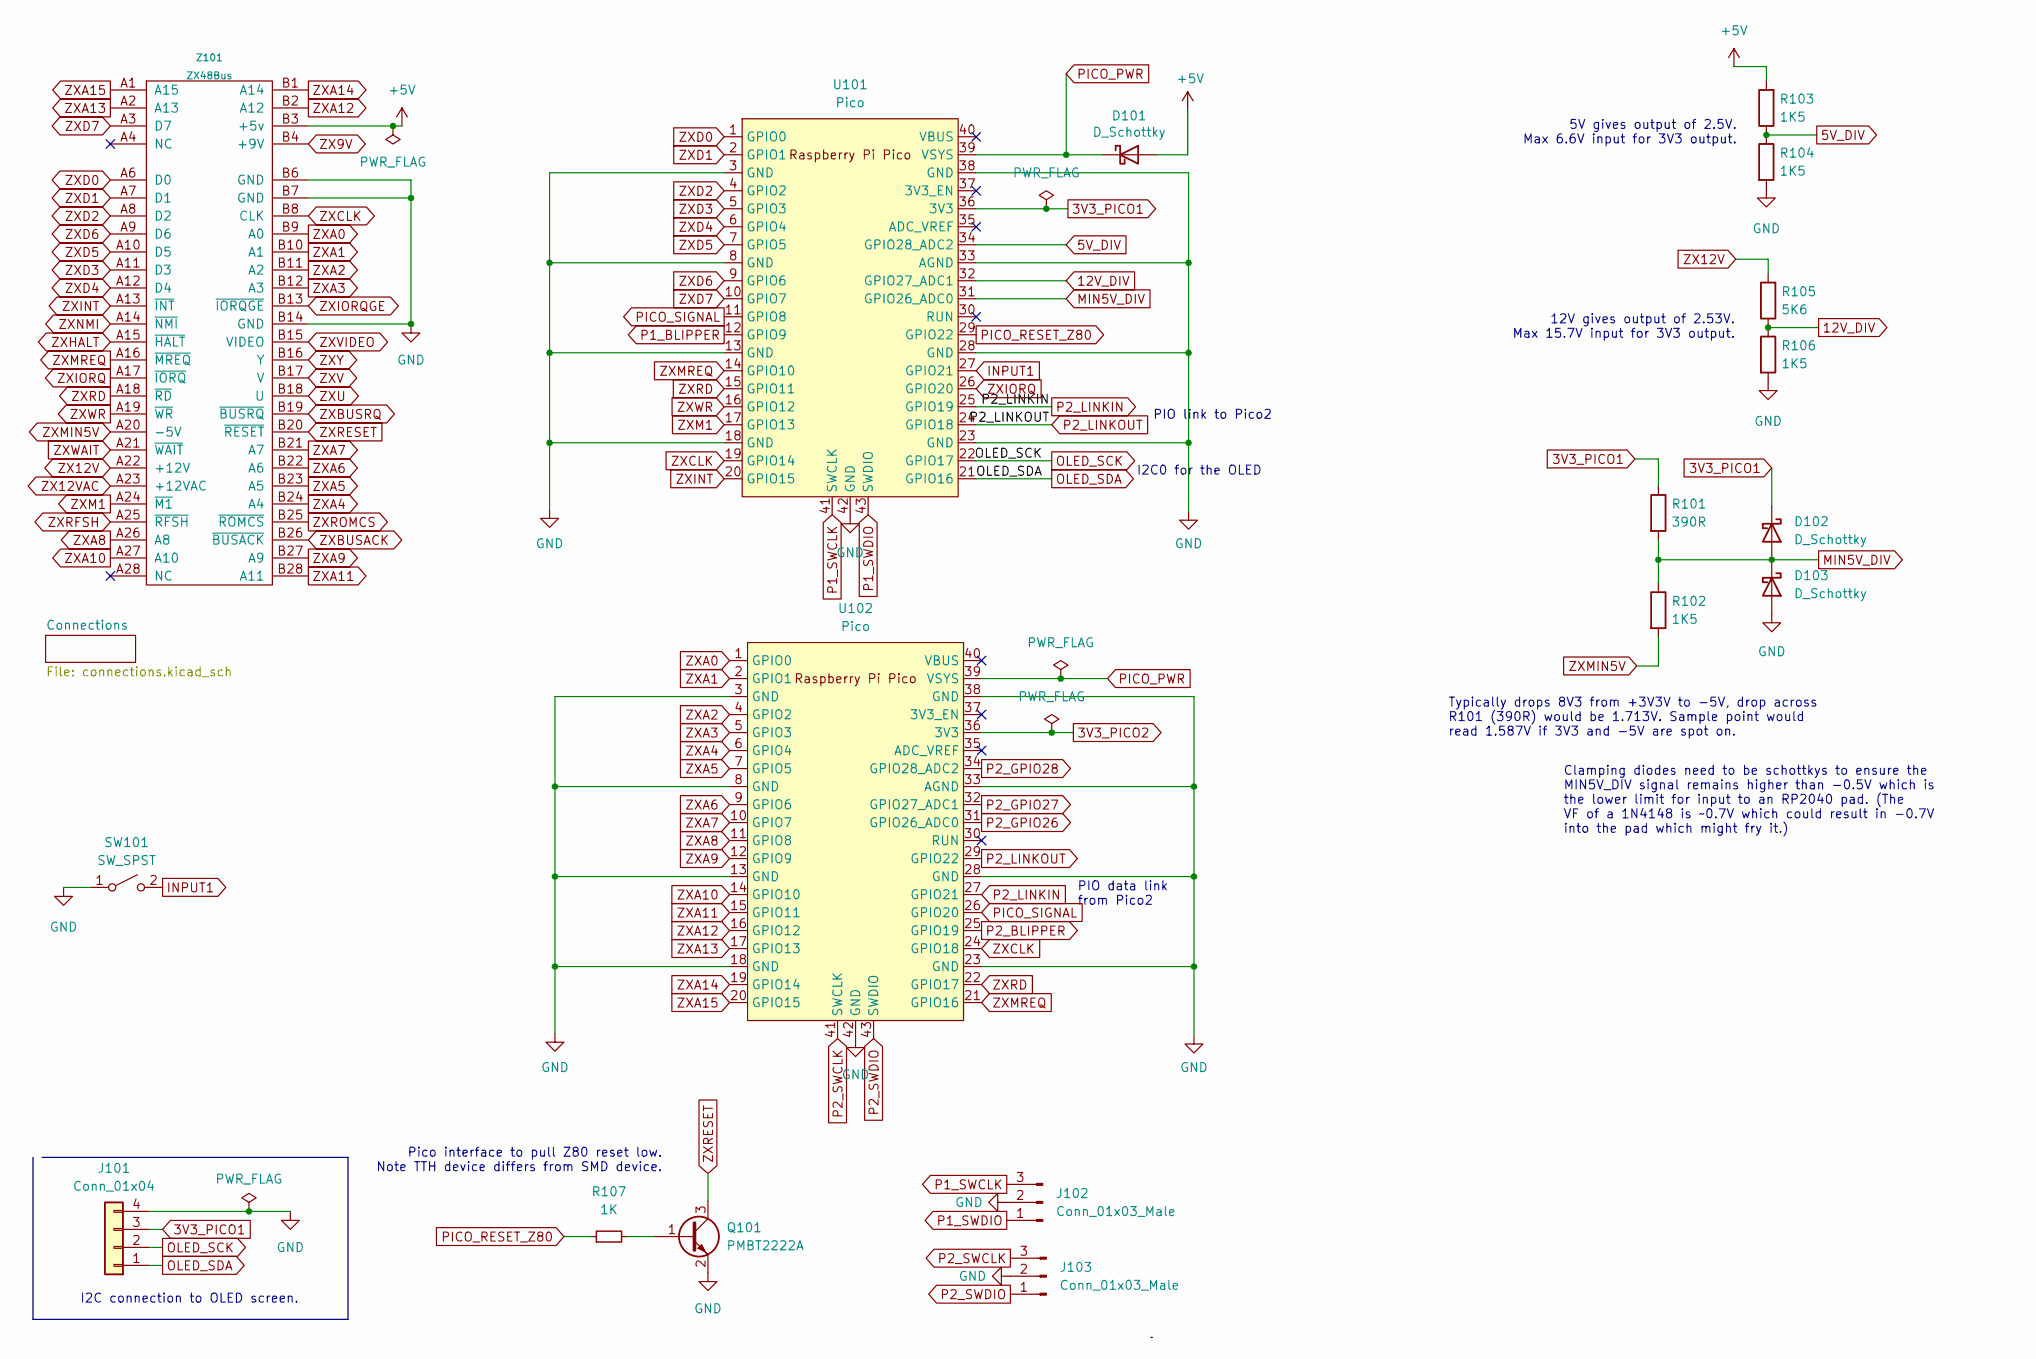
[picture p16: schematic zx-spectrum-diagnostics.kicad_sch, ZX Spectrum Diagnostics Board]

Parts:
D101, D102, D103: D_Schottky; D_1206_3216Metric_Pad1.42x1.75mm_HandSolder
J101: Conn_01x04; PinHeader_1x04_P2.54mm_Vertical
J102, J103: Conn_01x03_Male; PinSocket_1x03_P2.54mm_Vertical
Q101: PMBT2222A; TSOT-23_HandSoldering
R101: 390R; R_1206_3216Metric_Pad1.30x1.75mm_HandSolder
R102, R103, R104, R106: 1K5; R_1206_3216Metric_Pad1.30x1.75mm_HandSolder
R105: 5K6; R_1206_3216Metric_Pad1.30x1.75mm_HandSolder
R107: 1K; R_1206_3216Metric_Pad1.30x1.75mm_HandSolder
SW101: SW_SPST; SW_PUSH_6mm_H4.3mm
U101, U102: Pico; RPi_Pico_SMD_TH
Z101: ZX48Bus; Spectrum_Edge_Connector

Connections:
3V3_PICO1: D102.1 (K), J101.3, R101.1, U101.36 (3V3)
3V3_PICO2: U102.36 (3V3)
5V_DIV: R103.1, R104.1, U101.34 (GPIO28_ADC2); also elsewhere on the board
12V_DIV: R105.1, R106.1, U101.32 (GPIO27_ADC1); also elsewhere on the board
+5V: D101.2 (A), R103.2, Z101.B3 (+5v); also elsewhere on the board
GND: D103.2 (A), J101.4, J102.2, J103.2, Q101.2 (E), R104.2, R106.2, SW101.1 (A), U101.3 (GND), U101.8 (GND), U101.13 (GND), U101.18 (GND), U101.23 (GND), U101.28 (GND), U101.33 (AGND), U101.38 (GND), U101.42 (GND), U102.3 (GND), U102.8 (GND), U102.13 (GND), U102.18 (GND), U102.23 (GND), U102.28 (GND), U102.33 (AGND), U102.38 (GND), U102.42 (GND), Z101.B6 (GND), Z101.B7 (GND), Z101.B14 (GND)
INPUT1: SW101.2 (B), U101.27 (GPIO21)
MIN5V_DIV: D102.2 (A), D103.1 (K), R101.2, R102.1, U101.31 (GPIO26_ADC0); also elsewhere on the board
unnamed: Q101.1 (B), R107.2
OLED_SCK: J101.2, U101.22 (GPIO17)
OLED_SDA: J101.1, U101.21 (GPIO16)
P1_BLIPPER: U101.12 (GPIO9); also elsewhere on the board
P1_SWCLK: J102.3, U101.41 (SWCLK)
P1_SWDIO: J102.1, U101.43 (SWDIO)
P2_BLIPPER: U102.25 (GPIO19); also elsewhere on the board
P2_GPIO26: U102.31 (GPIO26_ADC0); also elsewhere on the board
P2_GPIO27: U102.32 (GPIO27_ADC1); also elsewhere on the board
P2_GPIO28: U102.34 (GPIO28_ADC2); also elsewhere on the board
P2_LINKIN: U101.25 (GPIO19), U102.27 (GPIO21)
P2_LINKOUT: U101.24 (GPIO18), U102.29 (GPIO22)
P2_SWCLK: J103.3, U102.41 (SWCLK)
P2_SWDIO: J103.1, U102.43 (SWDIO)
PICO_PWR: D101.1 (K), U101.39 (VSYS), U102.39 (VSYS)
PICO_RESET_Z80: R107.1, U101.29 (GPIO22)
PICO_SIGNAL: U101.11 (GPIO8), U102.26 (GPIO20); also elsewhere on the board
ZX9V: Z101.B4 (+9V); also elsewhere on the board
ZX12V: R105.2, Z101.A22 (+12V); also elsewhere on the board
ZX12VAC: Z101.A23 (+12VAC)
ZXA0: U102.1 (GPIO0), Z101.B9 (A0); also elsewhere on the board
ZXA1: U102.2 (GPIO1), Z101.B10 (A1); also elsewhere on the board
ZXA2: U102.4 (GPIO2), Z101.B11 (A2); also elsewhere on the board
ZXA3: U102.5 (GPIO3), Z101.B12 (A3); also elsewhere on the board
ZXA4: U102.6 (GPIO4), Z101.B24 (A4); also elsewhere on the board
ZXA5: U102.7 (GPIO5), Z101.B23 (A5); also elsewhere on the board
ZXA6: U102.9 (GPIO6), Z101.B22 (A6); also elsewhere on the board
ZXA7: U102.10 (GPIO7), Z101.B21 (A7); also elsewhere on the board
ZXA8: U102.11 (GPIO8), Z101.A26 (A8); also elsewhere on the board
ZXA9: U102.12 (GPIO9), Z101.B27 (A9); also elsewhere on the board
ZXA10: U102.14 (GPIO10), Z101.A27 (A10); also elsewhere on the board
ZXA11: U102.15 (GPIO11), Z101.B28 (A11); also elsewhere on the board
ZXA12: U102.16 (GPIO12), Z101.B2 (A12); also elsewhere on the board
ZXA13: U102.17 (GPIO13), Z101.A2 (A13); also elsewhere on the board
ZXA14: U102.19 (GPIO14), Z101.B1 (A14); also elsewhere on the board
ZXA15: U102.20 (GPIO15), Z101.A1 (A15); also elsewhere on the board
ZXBUSACK: Z101.B26 (~BUSACK); also elsewhere on the board
ZXBUSRQ: Z101.B19 (~BUSRQ); also elsewhere on the board
ZXCLK: U101.19 (GPIO14), U102.24 (GPIO18), Z101.B8 (CLK); also elsewhere on the board
ZXD0: U101.1 (GPIO0), Z101.A6 (D0); also elsewhere on the board
ZXD1: U101.2 (GPIO1), Z101.A7 (D1); also elsewhere on the board
ZXD2: U101.4 (GPIO2), Z101.A8 (D2); also elsewhere on the board
ZXD3: U101.5 (GPIO3), Z101.A11 (D3); also elsewhere on the board
ZXD4: U101.6 (GPIO4), Z101.A12 (D4); also elsewhere on the board
ZXD5: U101.7 (GPIO5), Z101.A10 (D5); also elsewhere on the board
ZXD6: U101.9 (GPIO6), Z101.A9 (D6); also elsewhere on the board
ZXD7: U101.10 (GPIO7), Z101.A3 (D7); also elsewhere on the board
ZXHALT: Z101.A15 (~HALT); also elsewhere on the board
ZXINT: U101.20 (GPIO15), Z101.A13 (~INT); also elsewhere on the board
ZXIORQ: U101.26 (GPIO20), Z101.A17 (~IORQ); also elsewhere on the board
ZXIORQGE: Z101.B13 (~IORQGE); also elsewhere on the board
ZXM1: U101.17 (GPIO13), Z101.A24 (~M1); also elsewhere on the board
ZXMIN5V: R102.2, Z101.A20 (-5V); also elsewhere on the board
ZXMREQ: U101.14 (GPIO10), U102.21 (GPIO16), Z101.A16 (~MREQ); also elsewhere on the board
ZXNMI: Z101.A14 (~NMI); also elsewhere on the board
ZXRD: U101.15 (GPIO11), U102.22 (GPIO17), Z101.A18 (~RD); also elsewhere on the board
ZXRESET: Q101.3 (C), Z101.B20 (~RESET); also elsewhere on the board
ZXRFSH: Z101.A25 (~RFSH); also elsewhere on the board
ZXROMCS: Z101.B25 (~ROMCS); also elsewhere on the board
ZXU: Z101.B18 (U); also elsewhere on the board
ZXV: Z101.B17 (V); also elsewhere on the board
ZXVIDEO: Z101.B15 (VIDEO); also elsewhere on the board
ZXWAIT: Z101.A21 (~WAIT); also elsewhere on the board
ZXWR: U101.16 (GPIO12), Z101.A19 (~WR); also elsewhere on the board
ZXY: Z101.B16 (Y); also elsewhere on the board

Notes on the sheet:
5V gives output of 2.5V. Max 6.6V input for 3V3 output.
PIO data link from Pico2
I2C connection to OLED screen.
I2C0 for the OLED
PIO link to Pico2
Pico interface to pull Z80 reset low. Note TTH device differs from SMD device.
Typically drops 8V3 from +3V3V to -5V, drop across R101 (390R) would be 1.713V. Sample point would read 1.587V if 3V3 and -5V are spot on.
Clamping diodes need to be schottkys to ensure the MIN5V_DIV signal remains higher than -0.5V which is the lower limit for input to an RP2040 pad. (The VF of a 1N4148 is ~0.7V which could result in -0.7V into the pad which might fry it.)
12V gives output of 2.53V. Max 15.7V input for 3V3 output.

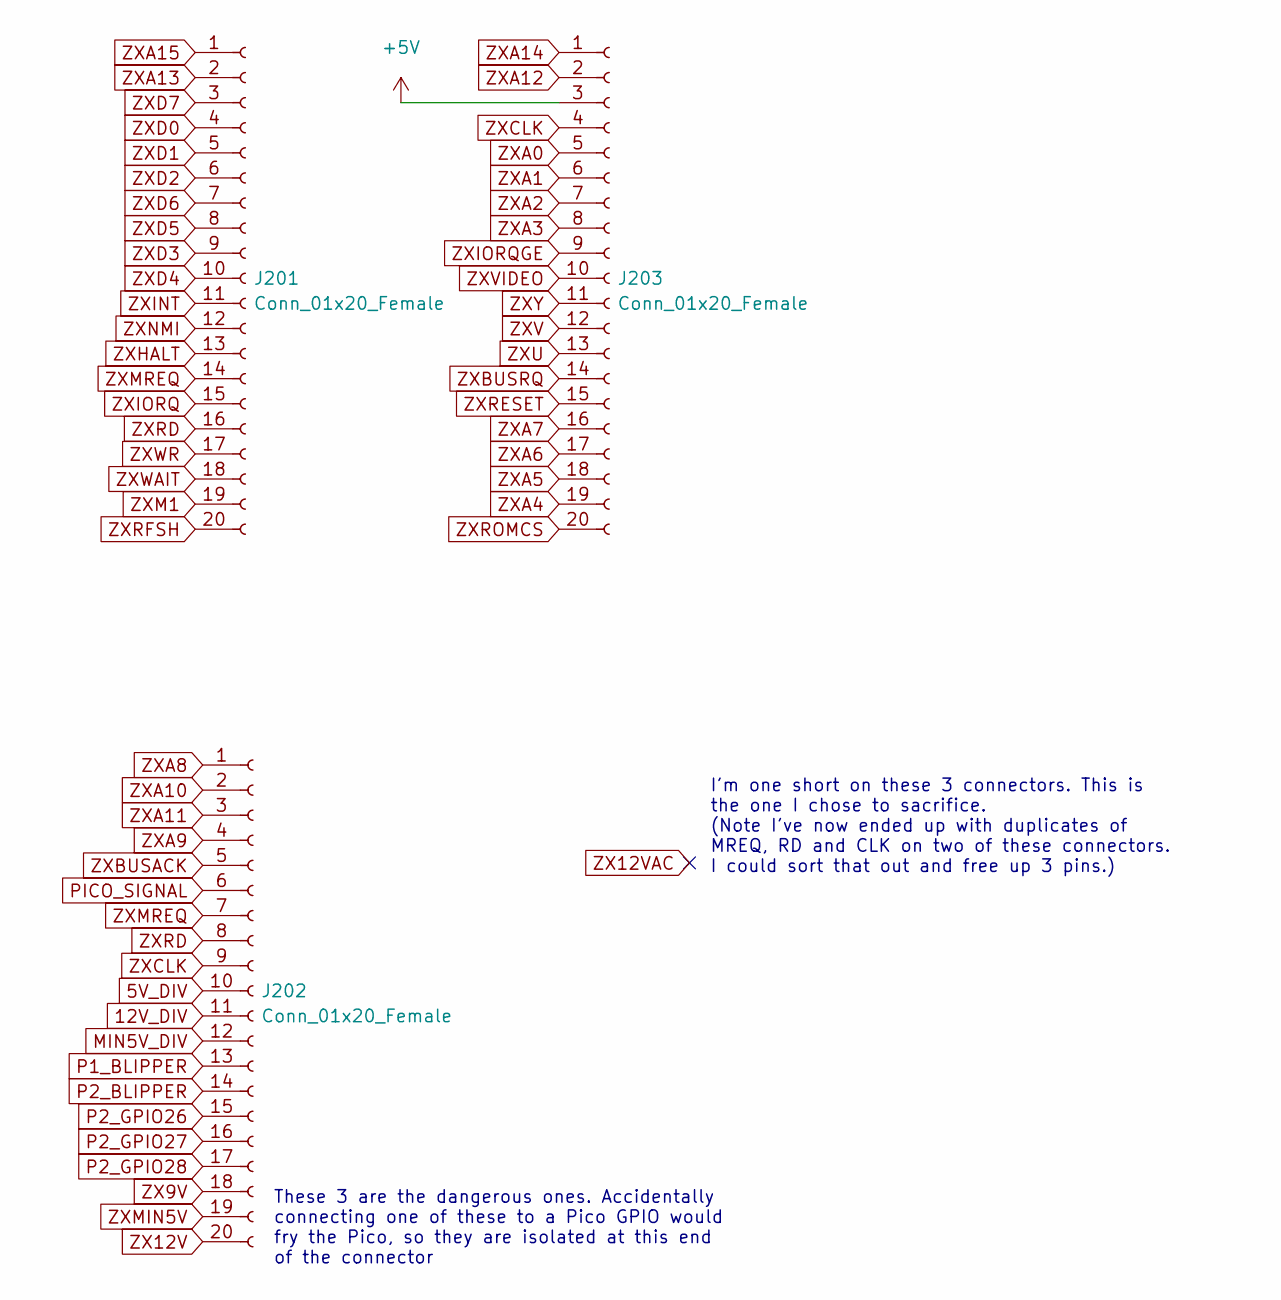
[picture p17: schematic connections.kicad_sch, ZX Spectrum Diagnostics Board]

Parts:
J201, J202, J203: Conn_01x20_Female; PinSocket_1x20_P2.54mm_Vertical

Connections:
5V_DIV: J202.10; also elsewhere on the board
12V_DIV: J202.11; also elsewhere on the board
+5V: J203.3; also elsewhere on the board
MIN5V_DIV: J202.12; also elsewhere on the board
P1_BLIPPER: J202.13; also elsewhere on the board
P2_BLIPPER: J202.14; also elsewhere on the board
P2_GPIO26: J202.15; also elsewhere on the board
P2_GPIO27: J202.16; also elsewhere on the board
P2_GPIO28: J202.17; also elsewhere on the board
PICO_SIGNAL: J202.6; also elsewhere on the board
ZX9V: J202.18; also elsewhere on the board
ZX12V: J202.20; also elsewhere on the board
ZXA0: J203.5; also elsewhere on the board
ZXA1: J203.6; also elsewhere on the board
ZXA2: J203.7; also elsewhere on the board
ZXA3: J203.8; also elsewhere on the board
ZXA4: J203.19; also elsewhere on the board
ZXA5: J203.18; also elsewhere on the board
ZXA6: J203.17; also elsewhere on the board
ZXA7: J203.16; also elsewhere on the board
ZXA8: J202.1; also elsewhere on the board
ZXA9: J202.4; also elsewhere on the board
ZXA10: J202.2; also elsewhere on the board
ZXA11: J202.3; also elsewhere on the board
ZXA12: J203.2; also elsewhere on the board
ZXA13: J201.2; also elsewhere on the board
ZXA14: J203.1; also elsewhere on the board
ZXA15: J201.1; also elsewhere on the board
ZXBUSACK: J202.5; also elsewhere on the board
ZXBUSRQ: J203.14; also elsewhere on the board
ZXCLK: J202.9, J203.4; also elsewhere on the board
ZXD0: J201.4; also elsewhere on the board
ZXD1: J201.5; also elsewhere on the board
ZXD2: J201.6; also elsewhere on the board
ZXD3: J201.9; also elsewhere on the board
ZXD4: J201.10; also elsewhere on the board
ZXD5: J201.8; also elsewhere on the board
ZXD6: J201.7; also elsewhere on the board
ZXD7: J201.3; also elsewhere on the board
ZXHALT: J201.13; also elsewhere on the board
ZXINT: J201.11; also elsewhere on the board
ZXIORQ: J201.15; also elsewhere on the board
ZXIORQGE: J203.9; also elsewhere on the board
ZXM1: J201.19; also elsewhere on the board
ZXMIN5V: J202.19; also elsewhere on the board
ZXMREQ: J201.14, J202.7; also elsewhere on the board
ZXNMI: J201.12; also elsewhere on the board
ZXRD: J201.16, J202.8; also elsewhere on the board
ZXRESET: J203.15; also elsewhere on the board
ZXRFSH: J201.20; also elsewhere on the board
ZXROMCS: J203.20; also elsewhere on the board
ZXU: J203.13; also elsewhere on the board
ZXV: J203.12; also elsewhere on the board
ZXVIDEO: J203.10; also elsewhere on the board
ZXWAIT: J201.18; also elsewhere on the board
ZXWR: J201.17; also elsewhere on the board
ZXY: J203.11; also elsewhere on the board

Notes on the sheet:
These 3 are the dangerous ones. Accidentally connecting one of these to a Pico GPIO would fry the Pico, so they are isolated at this end of the connector
I'm one short on these 3 connectors. This is the one I chose to sacrifice. (Note I've now ended up with duplicates of MREQ, RD and CLK on two of these connectors. I could sort that out and free up 3 pins.)

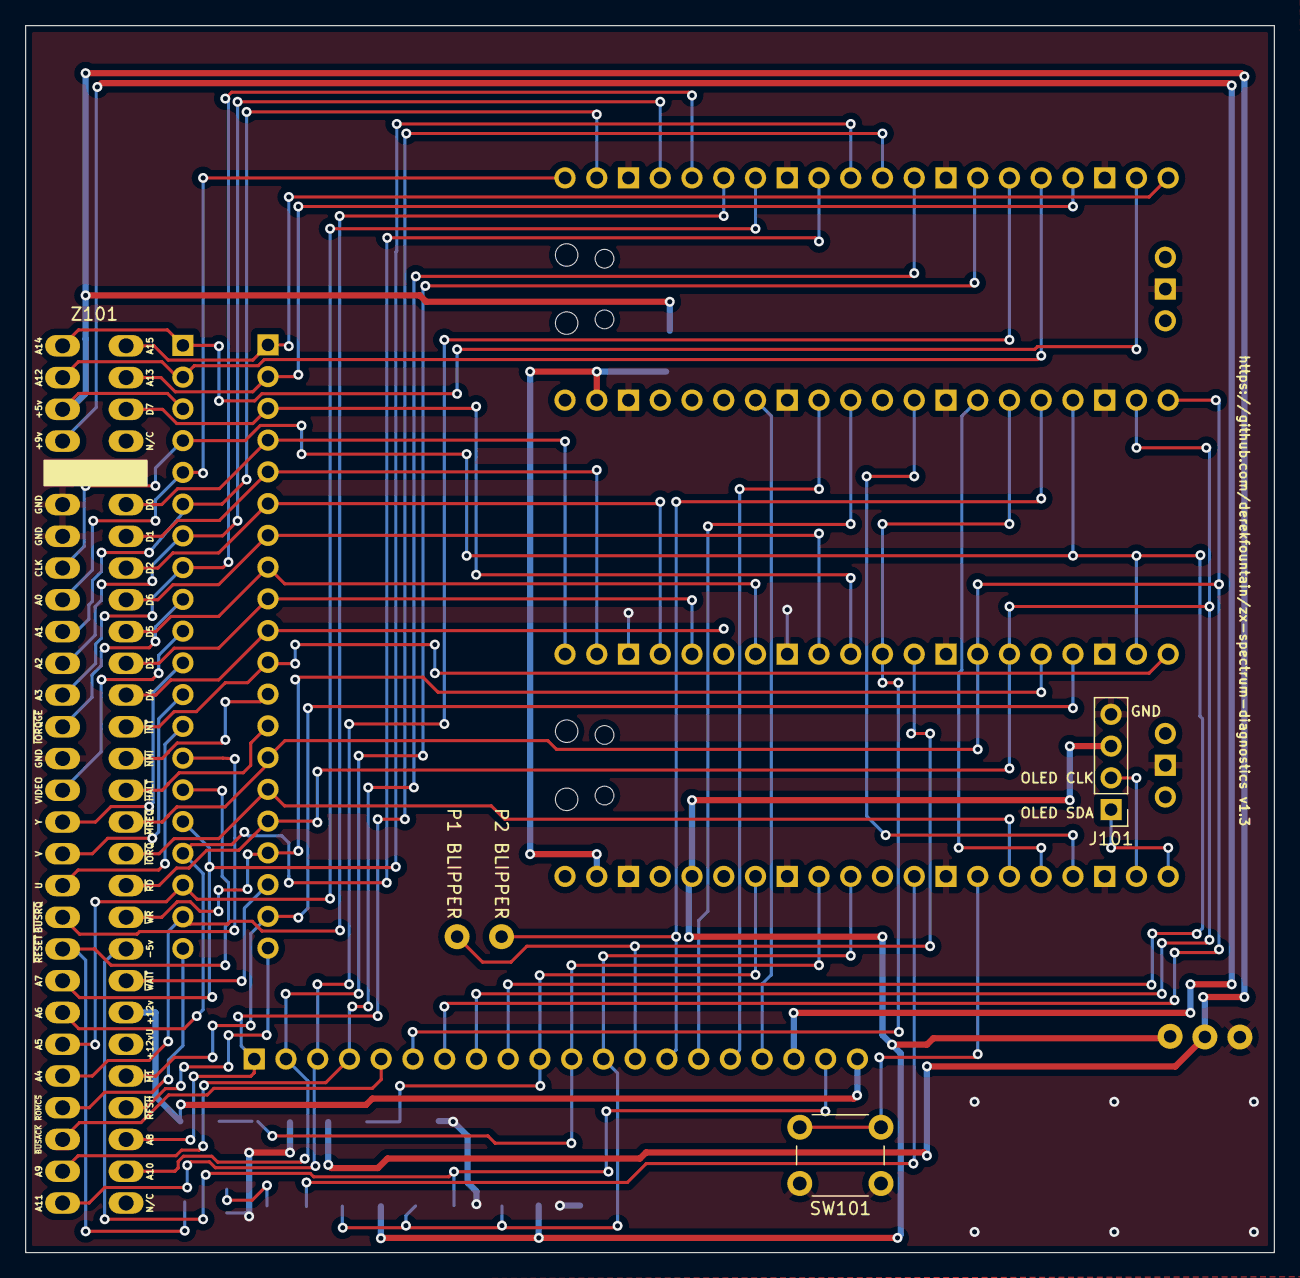
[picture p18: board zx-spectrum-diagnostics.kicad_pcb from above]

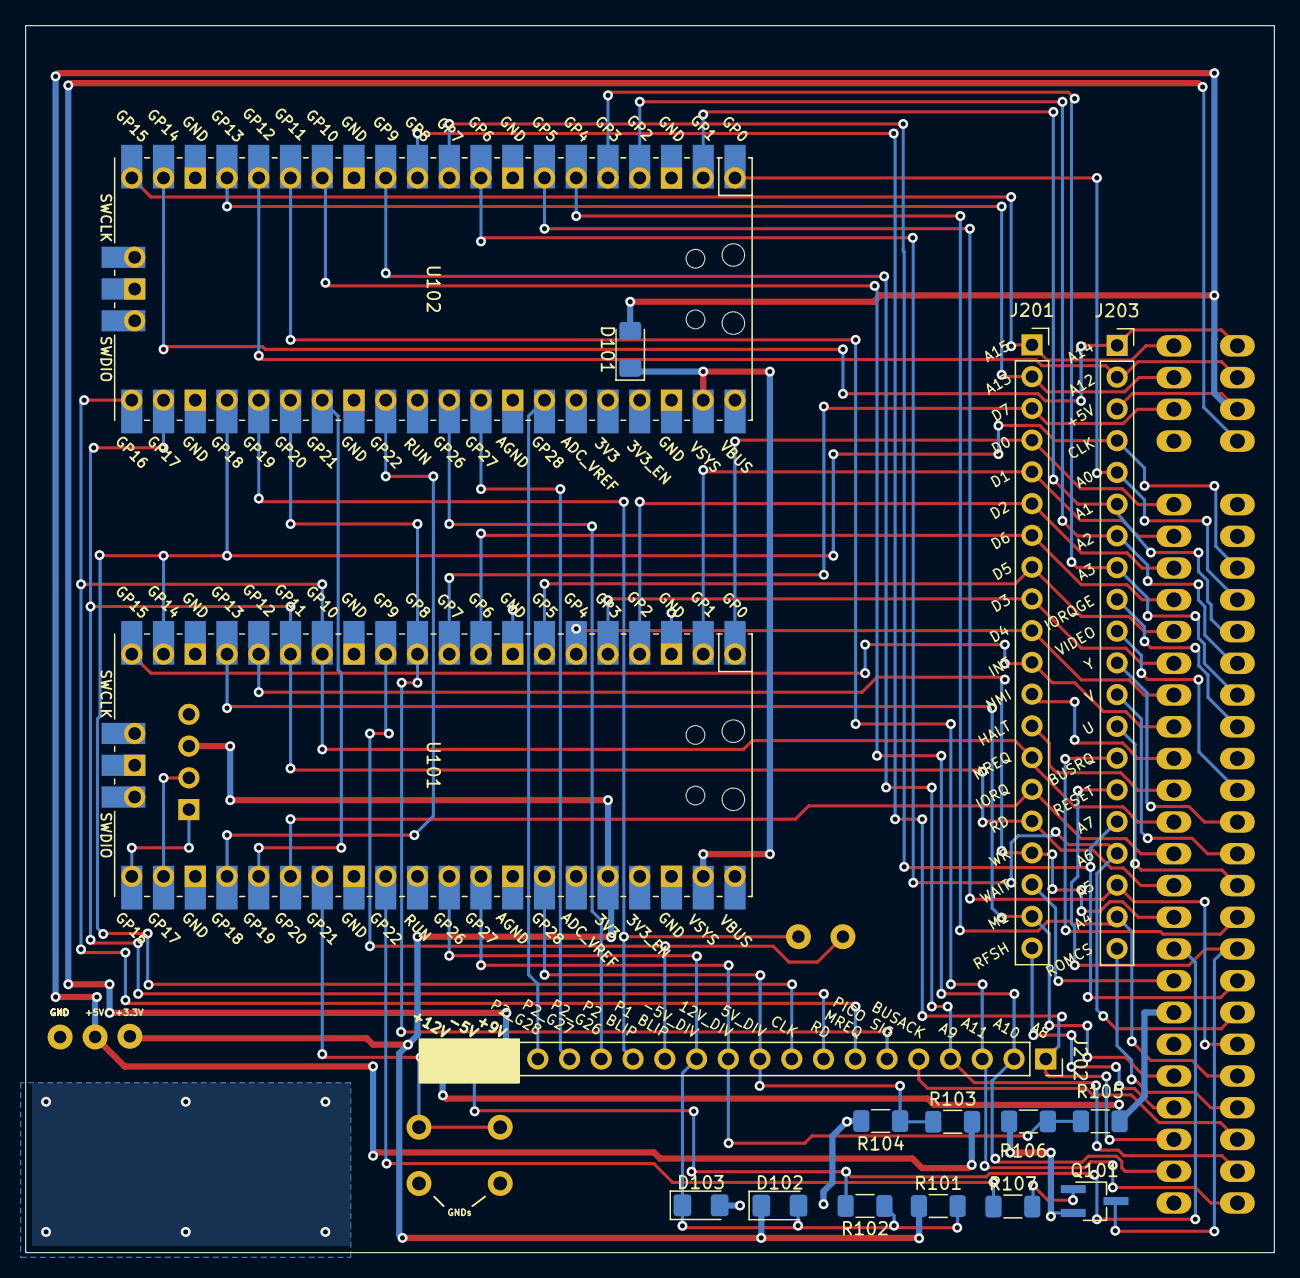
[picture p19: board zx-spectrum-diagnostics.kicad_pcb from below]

Board: 2 copper layers, 99.9 x 98.2 mm, 19 parts (16 on the bottom side), 67 nets.

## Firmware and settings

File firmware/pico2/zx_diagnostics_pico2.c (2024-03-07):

/*
 * ZX Diagnostics Firmware, a Raspberry Pi Pico based Spectrum test device
 * Copyright (C) 2024 Derek Fountain
 * 
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
 * You should have received a copy of the GNU General Public License
 * along with this program; if not, write to the Free Software
 * Foundation, Inc., 51 Franklin Street, Fifth Floor, Boston, MA  02110-1301, USA.
 */

/*
 * cmake -DCMAKE_BUILD_TYPE=Debug ..
 * make -j10
 * sudo openocd -f interface/picoprobe.cfg -f target/rp2040.cfg -c "program ./zx_diagnostics_pico2.elf verify reset exit"
 * sudo openocd -f interface/picoprobe.cfg -f target/rp2040.cfg
 * gdb-multiarch ./zx_diagnostics_pico2.elf
 *  target remote localhost:3333
 *  load
 *  monitor reset init
 *  continue
 */

#define _GNU_SOURCE      /* Expose memmem() in string.h */

#include "pico/platform.h"
#include "pico/stdlib.h"
#include "pico/binary_info.h"
#include <string.h>

#include "test_data.h"
#include "gpios.h"

#include "link_common.h"
#include "picoputer.pio.h"

/* Test indicators, one of these is sent by Pico1 to say which test we are to run */
#define PICO_COMM_TEST_ABUS 0x01020304
#define PICO_COMM_TEST_ROM  0x04030201

static void test_blipper( void )
{
  gpio_put( GPIO_P2_BLIPPER, 1 );
  __asm volatile ("nop");
  __asm volatile ("nop");
  __asm volatile ("nop");
  __asm volatile ("nop");
  gpio_put( GPIO_P2_BLIPPER, 0 );
}

/*
 * Code for the second Pico. This one has the address bus lines connected
 * to GPIOs 0-15. It sits waiting for an instruction from Pico1 to arrive
 * on the Pico-Pico link. That instruction consists of an indication of
 * which test it's expected to run. Once that's arrived it spins on a GPIO
 * controlled by Pico1. The moment that GPIO goes high, the test starts.
 * The test continues to run until the GPIO is pulled low again by Pico1.
 * It reports the result then goes back to waiting.
 */
void main( void )
{
  bi_decl(bi_program_description("ZX Spectrum Diagnostics Pico2 Board Binary."));

  /* Let the main Pico get going */
  sleep_ms( 2000 );

  /* Blipper, for the scope */
  gpio_init( GPIO_P2_BLIPPER ); gpio_set_dir( GPIO_P2_BLIPPER, GPIO_OUT ); gpio_put( GPIO_P2_BLIPPER, 0 );

  /* Watch for the incoming cue from the other Pico */
  gpio_init( GPIO_P2_SIGNAL );  gpio_set_dir( GPIO_P2_SIGNAL, GPIO_IN );  gpio_pull_down( GPIO_P2_SIGNAL );

  gpio_init( GPIO_ABUS_A0  );   gpio_set_dir( GPIO_ABUS_A0,  GPIO_IN ); gpio_pull_up( GPIO_ABUS_A0  );
  gpio_init( GPIO_ABUS_A1  );   gpio_set_dir( GPIO_ABUS_A1,  GPIO_IN ); gpio_pull_up( GPIO_ABUS_A1  );
  gpio_init( GPIO_ABUS_A2  );   gpio_set_dir( GPIO_ABUS_A2,  GPIO_IN ); gpio_pull_up( GPIO_ABUS_A2  );
  gpio_init( GPIO_ABUS_A3  );   gpio_set_dir( GPIO_ABUS_A3,  GPIO_IN ); gpio_pull_up( GPIO_ABUS_A3  );
  gpio_init( GPIO_ABUS_A4  );   gpio_set_dir( GPIO_ABUS_A4,  GPIO_IN ); gpio_pull_up( GPIO_ABUS_A4  );
  gpio_init( GPIO_ABUS_A5  );   gpio_set_dir( GPIO_ABUS_A5,  GPIO_IN ); gpio_pull_up( GPIO_ABUS_A5  );
  gpio_init( GPIO_ABUS_A6  );   gpio_set_dir( GPIO_ABUS_A6,  GPIO_IN ); gpio_pull_up( GPIO_ABUS_A6  );
  gpio_init( GPIO_ABUS_A7  );   gpio_set_dir( GPIO_ABUS_A7,  GPIO_IN ); gpio_pull_up( GPIO_ABUS_A7  );
  gpio_init( GPIO_ABUS_A8  );   gpio_set_dir( GPIO_ABUS_A8,  GPIO_IN ); gpio_pull_up( GPIO_ABUS_A8  );
  gpio_init( GPIO_ABUS_A9  );   gpio_set_dir( GPIO_ABUS_A9,  GPIO_IN ); gpio_pull_up( GPIO_ABUS_A9  );
  gpio_init( GPIO_ABUS_A10 );   gpio_set_dir( GPIO_ABUS_A10, GPIO_IN ); gpio_pull_up( GPIO_ABUS_A10 );
  gpio_init( GPIO_ABUS_A11 );   gpio_set_dir( GPIO_ABUS_A11, GPIO_IN ); gpio_pull_up( GPIO_ABUS_A11 );
  gpio_init( GPIO_ABUS_A12 );   gpio_set_dir( GPIO_ABUS_A12, GPIO_IN ); gpio_pull_up( GPIO_ABUS_A12 );
  gpio_init( GPIO_ABUS_A13 );   gpio_set_dir( GPIO_ABUS_A13, GPIO_IN ); gpio_pull_up( GPIO_ABUS_A13 );
  gpio_init( GPIO_ABUS_A14 );   gpio_set_dir( GPIO_ABUS_A14, GPIO_IN ); gpio_pull_up( GPIO_ABUS_A14 );
  gpio_init( GPIO_ABUS_A15 );   gpio_set_dir( GPIO_ABUS_A15, GPIO_IN ); gpio_pull_up( GPIO_ABUS_A15 );

  const uint LED_PIN = PICO_DEFAULT_LED_PIN;
  gpio_init(LED_PIN);
  gpio_set_dir(LED_PIN, GPIO_OUT);

  const enum gpio_function linkout_function = GPIO_FUNC_PIO0;
  const PIO                linkout_pio      = pio0;
  const enum gpio_function linkin_function  = GPIO_FUNC_PIO0;
  const PIO                linkin_pio       = pio0;

  /* Outbound link, to Pico1 */
  gpio_set_function(GPIO_P2_LINKOUT, linkout_function);

  int  linkout_sm = pio_claim_unused_sm(linkout_pio, true);
  uint offset     = pio_add_program(linkout_pio, &picoputerlinkout_program);
  picoputerlinkout_program_init(linkout_pio, linkout_sm, offset, GPIO_P2_LINKOUT);

  /* Inbound link, from Pico1 */
  gpio_set_function(GPIO_P2_LINKIN, linkin_function);

  int  linkin_sm  = pio_claim_unused_sm(linkin_pio, true);
       offset     = pio_add_program(linkin_pio, &picoputerlinkin_program);
  picoputerlinkin_program_init(linkin_pio, linkin_sm, offset, GPIO_P2_LINKIN);

  /* Let everything settle before this end starts listening */
  sleep_ms( 1000 );

  uint32_t test_counter = 0;
  while( 1 )
  {
    /* Wait for test type from the other Pico */
    uint32_t test_type = PICO_COMM_TEST_ABUS;
    ui_link_receive_buffer( linkin_pio, linkin_sm, linkout_sm, (uint8_t*)&test_type, sizeof(test_type) );

    /*
     * Pico1 has told this Pico to run a test. The requested test type is in test_type.
     * The signal to start the test is the GPIO_P2_SIGNAL going high, which is how the
     * first Pico drives it when it wants the test to start.
     */

    /* Read the GPIO_P2_SIGNAL, wait for it to go high */
    while( gpio_get( GPIO_P2_SIGNAL ) == 0 );

    /* Go! Run the requested test */
    switch( test_type )
    {
    case PICO_COMM_TEST_ABUS:
    {
      /*
       * Pico1 has asked for the address bus test. This test checks each of the Z80 address
       * lines and confirms each one is seeing going from high to low, and low to high.
       * As the Spectrum starts up you'd expect to see all lines make these transitions.
       * If one or more doesn't, that implies a stuck or unconnected address line.
       */

      /*
       * Address bus test, just monitor the address lines and confirm they got low->high and high->low
       * Loop while the first Pico is holding the "test running" signal
       */
      SEEN_EDGE line_edge[16] =	{ SEEN_NEITHER, SEEN_NEITHER, SEEN_NEITHER, SEEN_NEITHER, 
				  SEEN_NEITHER, SEEN_NEITHER, SEEN_NEITHER, SEEN_NEITHER, 
				  SEEN_NEITHER, SEEN_NEITHER, SEEN_NEITHER, SEEN_NEITHER, 
				  SEEN_NEITHER, SEEN_NEITHER, SEEN_NEITHER, SEEN_NEITHER };
      
      uint32_t previous_gpios_state = gpio_get_all() & 0x0000FFFF;

      while( gpio_get( GPIO_P2_SIGNAL ) == 1 )
      {
	/*
	 * Each iteration I loop over the 16 address lines looking for transitions.
	 * Previous GPIO state is taken at the very start. When a bit is seen going
	 * high to low, or low to high, the output array entry is updated and the
	 * previous bit store is updated.
	 * 
	 * SEEN_FALLING | SEEN_RISING = SEEN_BOTH
	 *
	 * (Imagine one bit: it starts at 0. I read it's state, it hasn't changed.
	 * Just keep looping until it changes to 1. It's seen rising. It's 
	 * previous-state is then set 1, and I loop. I read it's state again,
	 * this time with a previous-state of 1, so I'm now looking for a transition
	 * to 0. When I see that, it's been seen falling. Repeat for each of the
	 * 16 address lines.)
	 * 
	 * When all bits are at SEEN_BOTH, which would be the typical case with a
	 * healthy Spectrum, the test is complete. But I have nothing else to do
	 * do I keep looping.
	 */

	uint32_t current_gpios_state = gpio_get_all();

	/* Work along the address bus lines */
	for( uint32_t gpio_index = 0; gpio_index < 16; gpio_index++ )
	{
	  uint32_t mask = (1 << gpio_index);

	  uint32_t current_gpio_state  = current_gpios_state & mask;
	  
	  if( previous_gpios_state & mask )
	  {
	    /* This GPIO was previously set */

	    if( current_gpio_state )
	    {
	      /* It was set, it's still set, NOP */
	    }
	    else
	    {
	      /* It was set, it's now not set, it's gone high to low */
	      line_edge[gpio_index] |= SEEN_FALLING;

	      /* Clear the bit in the previous state, it's now unset */
	      previous_gpios_state &= ~mask;
	    }
	  }
	  else
	  {
	    /* This GPIO was previously unset */

	    if(! current_gpio_state )
	    {
	      /* It was unset, it's still unset, NOP */
	    }
	    else
	    {
	      /* It was unset, it's now set, it's gone low to high */
	      line_edge[gpio_index] |= SEEN_RISING;

	      /* Set the bit in the previous state, it's now set */
	      previous_gpios_state |= mask;
	    }
	  }

	} /* End for 16 address lines */     

      } /* End while P2 signal is held by Pico1 */

      /* Send response  - send buffer load */
      ui_link_send_buffer( linkout_pio, linkout_sm, linkin_sm, (uint8_t*)line_edge, sizeof(line_edge)*sizeof(line_edge[0]) );

      /* Send 32-bit raw GPIO state so other Pico can see what lines are stuck, if any */
      uint32_t gpio_state = gpio_get_all();
      ui_link_send_buffer( linkout_pio, linkout_sm, linkin_sm, (uint8_t*)&gpio_state, sizeof(gpio_state) );
    }
    break;



    case PICO_COMM_TEST_ROM:
    {
      /*
       * Pico1 has asked for the ROM test. This test checks that the Z80 asks for the
       * sequence of addresses of the start up program sequence in the Spectrum ROM,
       * thus proving that the Z80 is working and the ROM is supplying the instruction
       * bytes correctly.
       *
       * The Z80 is allowed to run (by Pico1) then the Z80 control bus lines are monitored
       * looking for memory reads. For each memory read, the address of the memory location
       * is stored away. The buffer for storing those addresses isn't very large, this
       * only checks the first few dozen expected instructions are fetched from the ROM.
       * It's assumed that if the Z80 runs the first few instructions from the ROM
       * correctly then everything must be running as expected.
       *
       * A complication is that the Z80 appears to restart several times. Looking at the
       * contents of the addresses buffer it shows it starts at 0000, goes to 0001, then
       * 0002, and then there's a burst of 0000s and it starts again. This happens about
       * 10 times, each restart getting a bit further than the last. Eventually the Z80
       * runs and doesn't restart. I think this is caused by jitter on the /RESET line.
       * It doesn't really matter for this test, other than to note that the contents
       * of the addresses buffer isn't a nice clean run from address 0000.
       */

      /*
       * With ADDR_BUF_SIZE=2048:
       *
       * (gdb) p sizeof(address_buffer)
       * $2 = 4096
       *
       * (gdb) x/1024xh address_buffer
       */
#define ADDR_BUF_SIZE 2048
      static uint16_t address_buffer[ADDR_BUF_SIZE];

      /* Clear buffer */
      uint32_t buffer_index = 0;
      for(buffer_index=0; buffer_index<ADDR_BUF_SIZE;buffer_index++)
	address_buffer[buffer_index] = 0;

      /*
       * This is the sequence of addresses the Z80 reads from as it starts running
       * the ROM program. The instruction at 0x11E0 is a jump back to the start of
       * the loop which does the RAM check. I chose that as the rather arbitrary
       * point to stop. If this sequence appears on the address bus the Z80 and
       * ROM are clearly communicating at least reasonably well.
       *
       * (gdb) p sizeof(expected_sequence)
       * $1 = 60
       *
       * (gdb) x/128xh expected_sequence
       */
      uint16_t expected_sequence[] = {
	0x0000, 0x0001, 0x0002, 0x0003,
	0x0004, 0x0005, 0x0006, 0x0007,
	0x11cb, 0x11cc, 0x11cd, 0x11ce,
	0x11cf, 0x11d0, 0x11d1, 0x11d2,
	0x11d3, 0x11d4, 0x11d5, 0x11d6,
	0x11d7, 0x11d8, 0x11d9, 0x11da,
	0x11db, 0x11dc, 0x11dd, 0x11de,
	0x11df, 0x11e0
      };

      buffer_index = 0;

      /* Loop while the first Pico is holding the "test running" signal */
      while( (gpio_get( GPIO_P2_SIGNAL ) == 1) && (buffer_index < ADDR_BUF_SIZE) )
      {
	/* Wait for a memory request to start */
	if( gpio_get( GPIO_Z80_MREQ ) == 0 )
	{
	  /* Wait for a read to start, as opposed to a write */
	  if( gpio_get( GPIO_Z80_RD ) == 0 )
	  {
	    /* OK, a Z80 memory read has begun, the address is already on the address bus */
	    uint16_t address_bus = gpio_get_all() & 0xFFFF;

	    /* Read the address bus, stash the value while there's room in the buffer */
	    address_buffer[buffer_index++] = address_bus;

	    /* Wait for the Z80 to complete the memory request */
	    while( gpio_get( GPIO_Z80_MREQ ) == 0 );

	  } /* Endif it's a RD */
	  
	} /* Endif if it's a MREQ */

      } /* End while P2 signal is held and the buffer isn't empty */

      /* Now try to find the expected sequence of addresses in the buffer of collected ones */
      uint32_t rom_sequence_match = 0;

      /* Find the expected address sequence in the collected address sequence */
      if( memmem( address_buffer, sizeof( address_buffer ), expected_sequence, sizeof( expected_sequence ) ) != NULL )
      {
	rom_sequence_match = 1;
      }

      /* Report result to the other Pico so it can update the screen */
      ui_link_send_buffer( linkout_pio, linkout_sm, linkin_sm, (uint8_t*)&rom_sequence_match, sizeof(uint32_t) );
    }
    break;

    default:
    {
      /*
       * Unknown test type. No idea what to do. It's probably just a glitch on
       * the line, it sometimes does that at startup. Pause for a moment to let
       * it settle (maybe, probably not actually helpful) then ignore it.
       */
      sleep_ms(1);
    }
    break;

    }

  }

}

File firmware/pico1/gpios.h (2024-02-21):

/* GPIOs for Pico1, the one with the data bus and most of the Z80 signals */

#ifndef __GPIOS_H
#define GPIOS_H

/* These need to match the hardware design */

/* Test signal to scope */
#define GPIO_P1_BLIPPER   9

/* I2C to screen */
#define GPIO_OLED_SDA    16
#define GPIO_OLED_SCK    17

/* Pico1 to Pico2 signal */
#define GPIO_P1_SIGNAL    8

/* Click on user button */
#define GPIO_INPUT1      21

/* Pico2 to Pico1 serial data link pin, input to Pico1 */
#define GPIO_P2_LINKOUT  18

/* Pico1 to Pico2 serial data link pin, input to Pico2 */
#define GPIO_P2_LINKIN   19

/* Output, holds Z80 in reset */
#define GPIO_Z80_RESET   22

#define GPIO_Z80_MREQ    10
#define GPIO_Z80_IORQ    20
#define GPIO_Z80_RD      11
#define GPIO_Z80_WR      12
#define GPIO_Z80_M1      13
#define GPIO_Z80_CLK     14
#define GPIO_Z80_INT     15

#define GPIO_DBUS_D0      0
#define GPIO_DBUS_D1      1
#define GPIO_DBUS_D2      2
#define GPIO_DBUS_D3      3
#define GPIO_DBUS_D4      4
#define GPIO_DBUS_D5      5
#define GPIO_DBUS_D6      6
#define GPIO_DBUS_D7      7

#endif

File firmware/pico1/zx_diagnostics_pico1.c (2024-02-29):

/*
 * ZX Diagnostics Firmware, a Raspberry Pi Pico based Spectrum test device
 * Copyright (C) 2024 Derek Fountain
 * 
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
 * You should have received a copy of the GNU General Public License
 * along with this program; if not, write to the Free Software
 * Foundation, Inc., 51 Franklin Street, Fifth Floor, Boston, MA  02110-1301, USA.
 */

/*
 * cmake -DCMAKE_BUILD_TYPE=Debug ..
 * make -j10
 * sudo openocd -f interface/picoprobe.cfg -f target/rp2040.cfg -c "program ./zx_diagnostics_pico1.elf verify reset exit"
 * sudo openocd -f interface/picoprobe.cfg -f target/rp2040.cfg
 * gdb-multiarch ./zx_diagnostics_pico1.elf
 *  target remote localhost:3333
 *  load
 *  monitor reset init
 *  continue
 */

#include <string.h>

#include "pico/platform.h"
#include "pico/stdlib.h"
#include "pico/binary_info.h"
#include "pico/multicore.h"

#include "page.h"
#include "oled.h"
#include "gpios.h"

#include "page_voltages.h"
#include "page_ula.h"
#include "page_z80.h"
#include "page_dbus.h"
#include "page_abus.h"
#include "page_rom.h"

#include "picoputer.pio.h"

static uint8_t input1_pressed = 0;

/* Set of pages, press button 1 to cycle these */
typedef enum
{
  VOLTAGE_PAGE = 0,
  ULA_PAGE,
  Z80_PAGE,
  DBUS_PAGE,
  ABUS_PAGE,
  ROM_PAGE,

  LAST_PAGE = ROM_PAGE
}
PAGE;

PAGE current_page;

/* All the tests the unit currently runs */
typedef enum
{
  TEST_VOLTAGE_5V     = 0,
  TEST_VOLTAGE_12V,
  TEST_VOLTAGE_MIN5V,
  TEST_VOLTAGE_AV5V,
  TEST_VOLTAGE_AV12V,
  TEST_VOLTAGE_AVMIN5V,

  TEST_ULA_INT,
  TEST_ULA_CLK,
  TEST_ULA_CCLK,

  TEST_Z80_M1,
  TEST_Z80_RD,
  TEST_Z80_WR,
  TEST_Z80_MREQ,

  TEST_DBUS_DBUS,

  TEST_ABUS_ABUS,

  TEST_ROM_SEQ,

  NUM_TESTS,
}
TEST_INDEX;

typedef enum
{
  NEEDS_RUNNING,
  RESULT_READY,
}
SHOW_RESULT_FLAG;

/* Inbound link, from second pico which does the address bus stuff */
static       int                linkin_sm;
static const PIO                linkin_pio      = pio1;
static const enum gpio_function linkin_function = GPIO_FUNC_PIO1;
static       uint               linkin_offset;

/* Outbound link, to second pico which does the address bus stuff */
static       int                linkout_sm;
static const PIO                linkout_pio      = pio1;
static const enum gpio_function linkout_function = GPIO_FUNC_PIO1;
static       uint               linkout_offset;

/* Paging, for the user interface */
typedef struct
{
  PAGE              page;
  uint8_t          *gui_title;
  void            (*init_func)(void);                       // Initialise
  void            (*gpio_func)( uint32_t, uint32_t );       // A GPIO line has changed state
  void            (*display_func)( void );                  // Display your output now
  SHOW_RESULT_FLAG  show_result;
}
DISPLAY_PAGE;

DISPLAY_PAGE page[] =
{
  { VOLTAGE_PAGE, "VOLTAGES",    voltage_page_init, NULL,               voltage_output, NEEDS_RUNNING },
  { ULA_PAGE,     "ULA SIGNALS", ula_page_init,     ula_page_gpios,     ula_output,     NEEDS_RUNNING },
  { Z80_PAGE,     "Z80 SIGNALS", z80_page_init,     z80_page_gpios,     z80_output,     NEEDS_RUNNING },
  { DBUS_PAGE,    "DATA BUS",    dbus_page_init,    dbus_page_gpios,    dbus_output,    NEEDS_RUNNING },
  { ABUS_PAGE,    "ADDRESS BUS", abus_page_init,    abus_page_gpios,    abus_output,    NEEDS_RUNNING },
  { ROM_PAGE,     "ROM",         rom_page_init,     rom_page_gpios,     rom_output,     NEEDS_RUNNING },
};
#define NUM_PAGES (sizeof(page) / sizeof(DISPLAY_PAGE))


/* From the timer_lowlevel.c example */
static uint64_t get_time_us( void )
{
  uint32_t lo = timer_hw->timelr;
  uint32_t hi = timer_hw->timehr;
  return ((uint64_t)hi << 32u) | lo;
}

/*
 * GPIO event handler callback. This manages the user input button, plus
 * any GPIO handling the tests require
 */
static uint64_t debounce_timestamp_us = 0;
void gpios_callback( uint gpio, uint32_t events ) 
{
  /*
   * Switch event, set to interrupt on rising edge, so this is a click up.
   */
  if( gpio == GPIO_INPUT1 )
  {
#define DEBOUNCE_USECS 100000
    /* Debounce pause, the switch is a bit noisy */
    if( (get_time_us() - debounce_timestamp_us) < DEBOUNCE_USECS )
    {
      /* If last switch action was very recently, assume it's a bounce and ignore it */
      debounce_timestamp_us = get_time_us();
    }
    else
    {
      /* Debounced, take action - just set a flag */
      if( gpio == GPIO_INPUT1 )
      {
	input1_pressed = 1;
      }

      /* Note this point as when we last actioned a switch */
      debounce_timestamp_us = get_time_us();
    }
  }
  else
  {
    /*
     * A GPIO (which isn't the user interface switches) has changed.
     * Pass the details into the code which is running the tests.
     */
    if( page[current_page].gpio_func != NULL )
    {
      (page[current_page].gpio_func)( gpio, events );
    }
  }
}
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

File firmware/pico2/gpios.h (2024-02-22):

/* GPIOs for Pico2, the one with the address bus */

#ifndef __GPIOS_H
#define GPIOS_H

/* These need to match the hardware design */

/* Test signal to scope */
#define GPIO_P2_BLIPPER   19

#define GPIO_ABUS_A0       0
#define GPIO_ABUS_A1       1
#define GPIO_ABUS_A2       2
#define GPIO_ABUS_A3       3
#define GPIO_ABUS_A4       4
#define GPIO_ABUS_A5       5
#define GPIO_ABUS_A6       6
#define GPIO_ABUS_A7       7
#define GPIO_ABUS_A8       8
#define GPIO_ABUS_A9       9
#define GPIO_ABUS_A10     10
#define GPIO_ABUS_A11     11
#define GPIO_ABUS_A12     12
#define GPIO_ABUS_A13     13
#define GPIO_ABUS_A14     14
#define GPIO_ABUS_A15     15

#define GPIO_Z80_MREQ     16
#define GPIO_Z80_RD       17
#define GPIO_Z80_CLK      18



#define GPIO_P2_SIGNAL    20

/* Pico2 to Pico1 serial data link pin, output from Pico2 */
#define GPIO_P2_LINKOUT   22

/* Pico2 to Pico1 serial data link pin, input to Pico2 */
#define GPIO_P2_LINKIN    21

#endif

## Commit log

2023-10-29 import various bits from other projects
    [zx-spectrum-diagnostics.kicad_pcb, zx-spectrum-diagnostics.kicad_sch]
2023-10-29 update schematic, add a second pico, tidy -5V sampler
    [zx-spectrum-diagnostics.kicad_sch]
2023-10-29 first layout
    [zx-spectrum-diagnostics.kicad_pcb, zx-spectrum-diagnostics.kicad_sch]
2023-11-04 back out previous layout, rearrange connections to match edge connector
    [connections.kicad_sch, zx-spectrum-diagnostics.kicad_pcb, zx-spectrum-diagnostics.kicad_sch]
2023-11-04 relaid, complete, needs tidying
    [zx-spectrum-diagnostics.kicad_pcb]
2023-11-04 lots more tidyups, nearly done
    [zx-spectrum-diagnostics.kicad_pcb]
2023-11-05 final, ready for fab
    [zx-spectrum-diagnostics.kicad_pcb]
2023-11-05 v1.0 off to fab
    [zx-spectrum-diagnostics-B_Cu.gbl, zx-spectrum-diagnostics-B_Mask.gbs, zx-spectrum-diagnostics-B_Paste.gbp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]
2023-11-13 build a bit of framework
2023-11-13 get a page reading voltages from the ADCs into place
2023-11-13 prepare some of the input button stuff
2023-11-14 add the scaling to the voltages, still no HW to test it on
2023-11-21 first board connected to spectrum, display working
2023-11-22 voltages displaying correctly on test machines
    [page_voltages.c]
2023-11-22 change the layout to use the proper edge connector
    [zx-spectrum-diagnostics.kicad_pcb, zx-spectrum-diagnostics.kicad_sch]
2023-11-27 add blipper, get the CLK reporting correctly (reset must be held, wire came out)
    [gpios.h, page_ula.c, zx_diagnostics_pico1.c]
2023-11-29 schematic reworked, it's time to relayout the board. checkpoint here
    [connections.kicad_sch, zx-spectrum-diagnostics.kicad_pcb, zx-spectrum-diagnostics.kicad_sch]
2023-11-29 sorted out the pico orientation and the edge connector connections
    [zx-spectrum-diagnostics.kicad_pcb, zx-spectrum-diagnostics.kicad_sch]
2023-11-30 just realised i've left J205 on the PCB! need to remove it and tidy up
    [zx-spectrum-diagnostics.kicad_pcb]
2023-11-30 connections all in place, many tidyups required
    [zx-spectrum-diagnostics.kicad_pcb]
2023-11-30 v1.1 ready to go? last checks
    [zx-spectrum-diagnostics.kicad_pcb]
2023-11-30 v1.1 off for fabrication
    [connections.kicad_sch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]
2023-12-22 v1.1 of the board working as well as v1.0 ever did
2024-01-24 start to fix the PIO loading/unloading
    [page_ula.c, zx_diagnostics_pico1.c]
2024-01-25 soldered the switch to my board, very basic paging working
2024-01-25 tweak the debounce on the switch to try to stop it interfering with the INT counter, CLK and cCLK swapping is back
    [zx_diagnostics_pico1.c]
2024-01-25 nail the weird CLK/cCLK value swapping bug
    [page_ula.c, zx_diagnostics_pico1.c]
2024-02-01 add ROM tests framework
2024-02-15 add averages to voltages page
2024-02-17 fix the stale data being shown issue
    [page_z80.c, zx_diagnostics_pico1.c]
2024-02-17 more refactoring the screen output, better handling of screen page switching
2024-02-17 better dbus test result, try to reflect stuck lines
    [page_dbus.c]
2024-02-19 add beginnings of a new pcb design based on the PGA2040
    [connections.kicad_sch, zx-spectrum-diagnostics.kicad_pcb, zx-spectrum-diagnostics.kicad_sch]
2024-02-19 remove button2, reuse GPIO for ZXIORQ
    [zx-spectrum-diagnostics.kicad_pcb, zx-spectrum-diagnostics.kicad_sch]
2024-02-20 basic comms between the picos established
    [zx-spectrum-diagnostics.kicad_sch]
2024-02-21 set up 2 way comms, use acknowledged byte transport
    [zx-spectrum-diagnostics.kicad_sch]
2024-02-22 have a required test value sent over to pico2 at the start. add test code to fill the address buffer. works but shows the odd restarting effect i saw when i was doing the ROM emulator
    [connections.kicad_sch, zx-spectrum-diagnostics.kicad_pcb, zx-spectrum-diagnostics.kicad_sch]
2024-03-07 debug for the -5V issue
    [page_voltages.c]
2024-03-09 add some notes about the -5V voltage divider
2024-03-11 rework the code to handle the rejigged -5V voltage divider
    [page_voltages.c]
2024-03-12 update schematic and PCB with revised -5V voltage divider
    [zx-spectrum-diagnostics.kicad_pcb, zx-spectrum-diagnostics.kicad_sch]
2024-03-12 update v1.2 pcb, add comments to PGS version, create v1.2 gerbers
    [connections.kicad_sch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]
2024-03-13 remove test points from v1.2, replace with GND area for clip. updated gerbers, sent for fabrication
    [zx-spectrum-diagnostics-B_Cu.gbl, zx-spectrum-diagnostics-B_Mask.gbs, zx-spectrum-diagnostics-B_Paste.gbp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]
2024-03-28 minor updates to labels on silkscreen
    [zx-spectrum-diagnostics.kicad_pcb]

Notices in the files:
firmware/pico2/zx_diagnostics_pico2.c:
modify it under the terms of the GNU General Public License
